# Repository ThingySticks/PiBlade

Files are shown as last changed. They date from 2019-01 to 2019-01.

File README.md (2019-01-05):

# Pi Blade

A 2U high "Blade" center for the Raspberry Pi (or many).

Design inspired by (1) which was inspired by (2) to use the DAP Audio 2 HE Rackblende f. Modulsystem 10 Segmente MP-1 (3), a 2U rack mount system with 10x 44mm wide panels.

## Rack Enclosure

This is the main intended enclosure, if the DAP Audio one isn't available this might be useful, hopefully some add-on bits for the modulsystem as well.

This is made of a number of parts.

* PiRackfrontPanel.svg/dxf - this is a 2U high laser cuttable version of the DAP Audio 2 HE Rackblende f. Modulsystem 10 Segmente MP-1. If you can't get the rack or don't want to wait (or don't mind an acrylic version this might work...

* PiRackRearSide.stl - a 3D printable 1/3 enclosure (side panel). 
** Intended to to around the back of the laser cut panel (not sure how well it will work with the proper rack).
** Print 2x of these, one for each side, then the middle section, these screw to the back of the laser cut acrylic.

## Standalone Enclosure

When getting the Pi's ready you probably don't want to put them in the rack, so this little barn style enclosure allows the blade to be screwed into it to hold it. The Fusion 360 design is scalable to allow multiple units.

* PiBarn-1.stl - 1 blade high
* PiBarn-3.stl - 3 blades high

# Front Panels

These consist of 3D printed panels () and are screwed to the blades.

* McPiFace - is a PCB panel, this can be sent to a fab house such as OSH Park to nicly make the panels.
* Panels from https://www.thingiverse.com/thing:2759317 can also be used and mounted onto the "Blades"

# Blades

These are the carrier frames for the Pi's. Compatible with https://www.thingiverse.com/thing:2759317

* PiRackPiBase.stl - this is the basic Pi blade base.
* PiRackPiLongBase.stl - this will hold 2x Pi's back to back, or HAT base from the Pi Sandwich https://github.com/ThingySticks/PiHatSandwich
** Obviously network connectivity is an issue for the second rear pi when mounting 2x Pi's.

## References

(1) https://www.thingiverse.com/thing:2759317
(2) https://www.thingiverse.com/thing:1793758
(3) https://www.musicstore.de/en_GB/GBP/DAP-Audio-2-HE-Rackblende-f-Modulsystem-10-Segmente-MP-1/art-PAH0017160-000

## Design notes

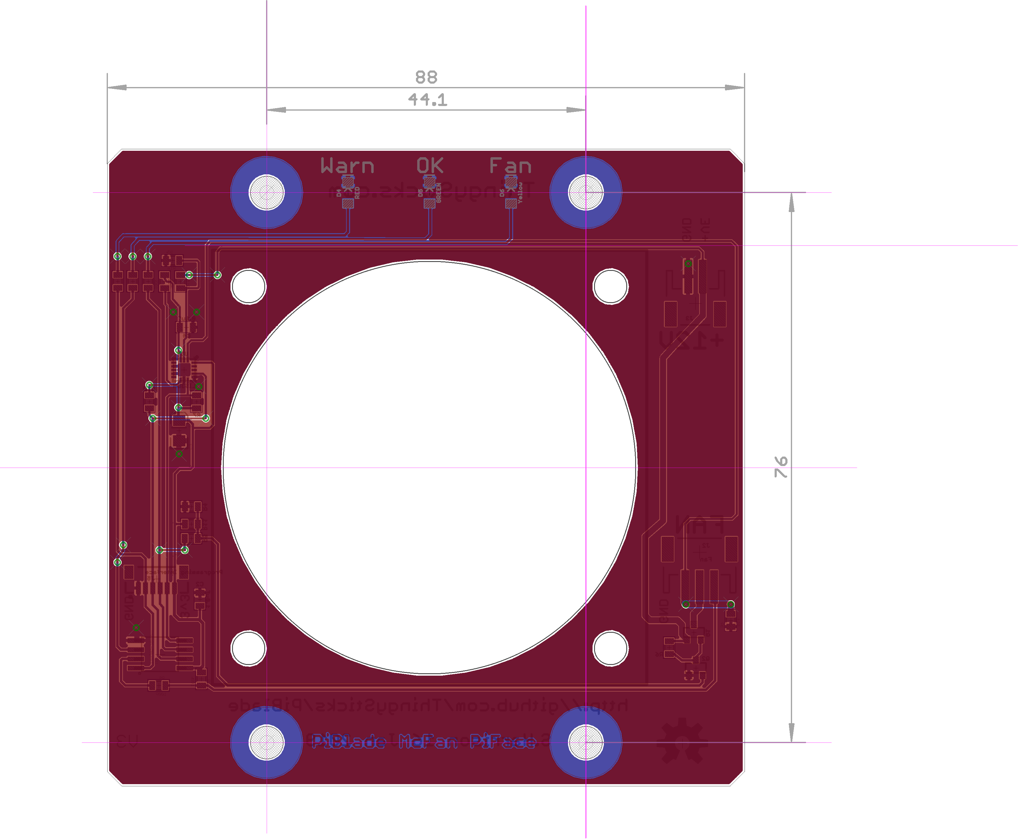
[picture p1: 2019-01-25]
FrontPanels/McPiFace/Images/Fan-V3/PcbAllLayersDesign.png

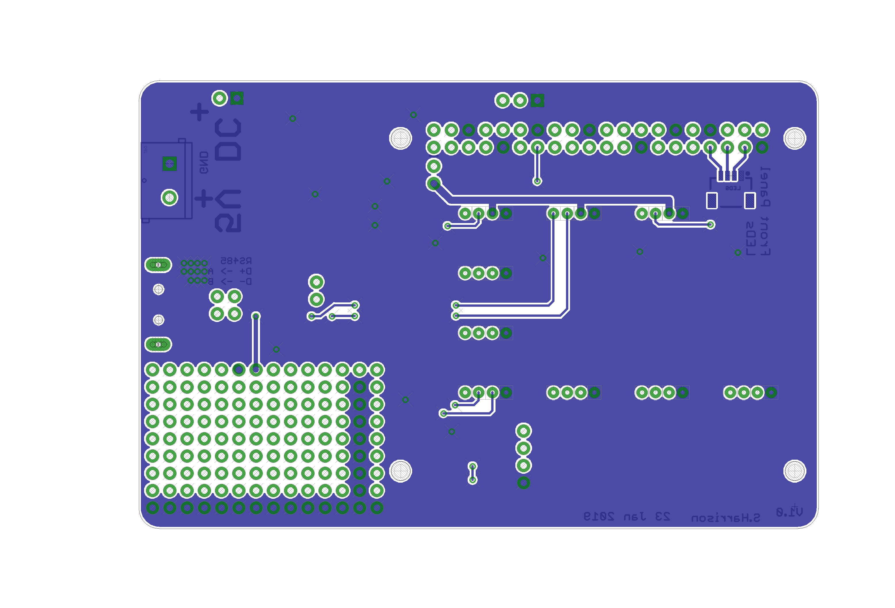
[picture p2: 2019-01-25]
Boards/PiBackPlaneConnector/Images/PcbBottomDesign.png

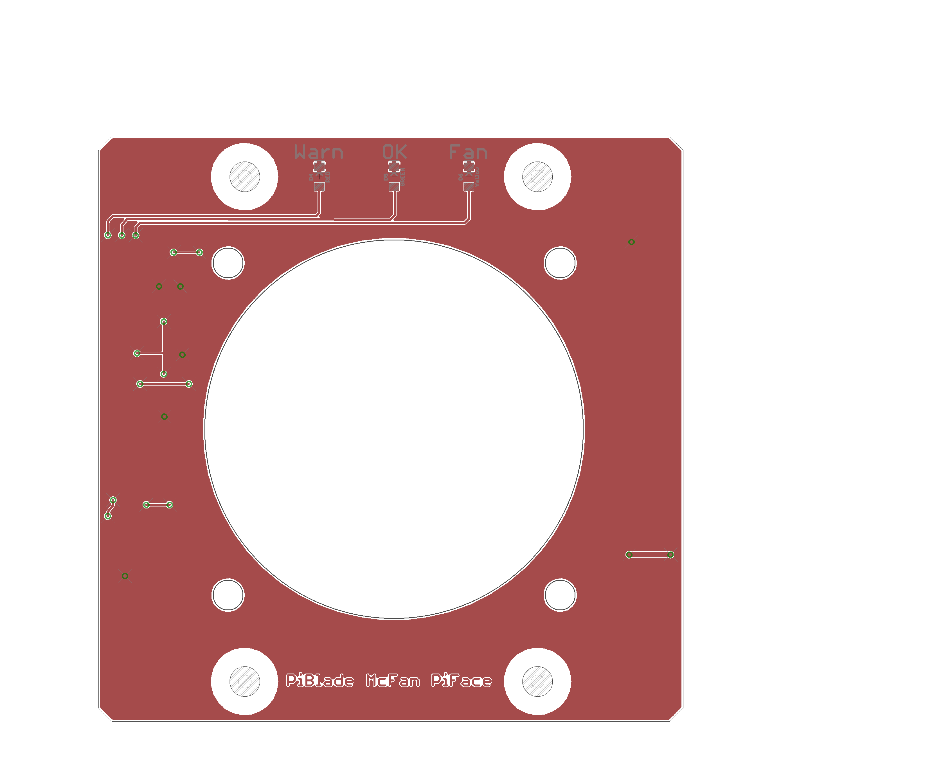
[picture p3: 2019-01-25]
FrontPanels/McPiFace/Images/Fan-V3/PcbTopDesign.png

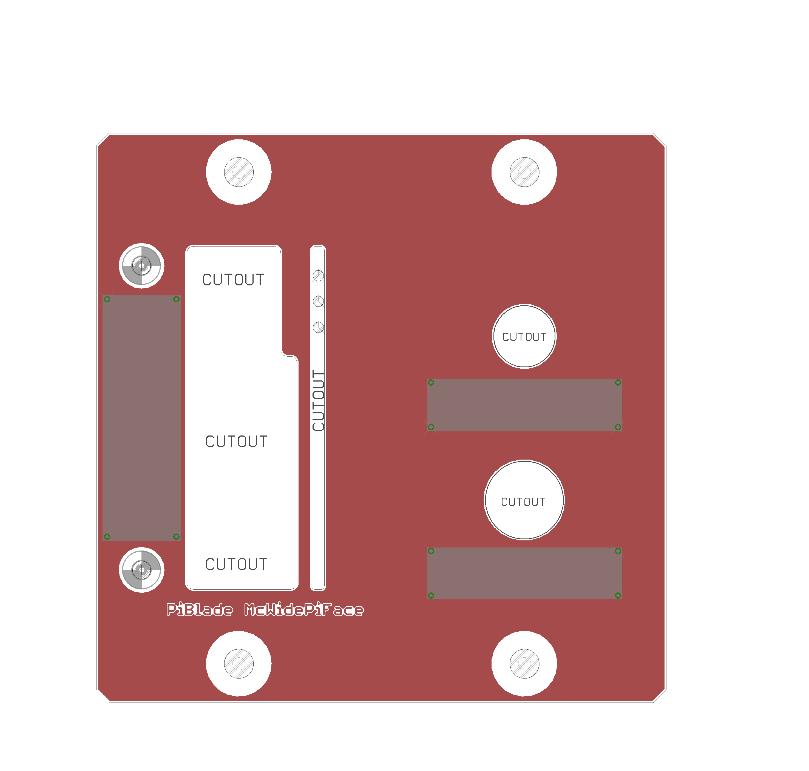
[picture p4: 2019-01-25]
FrontPanels/McPiFace/Images/Double - Aerial/PcbTopDesign.png

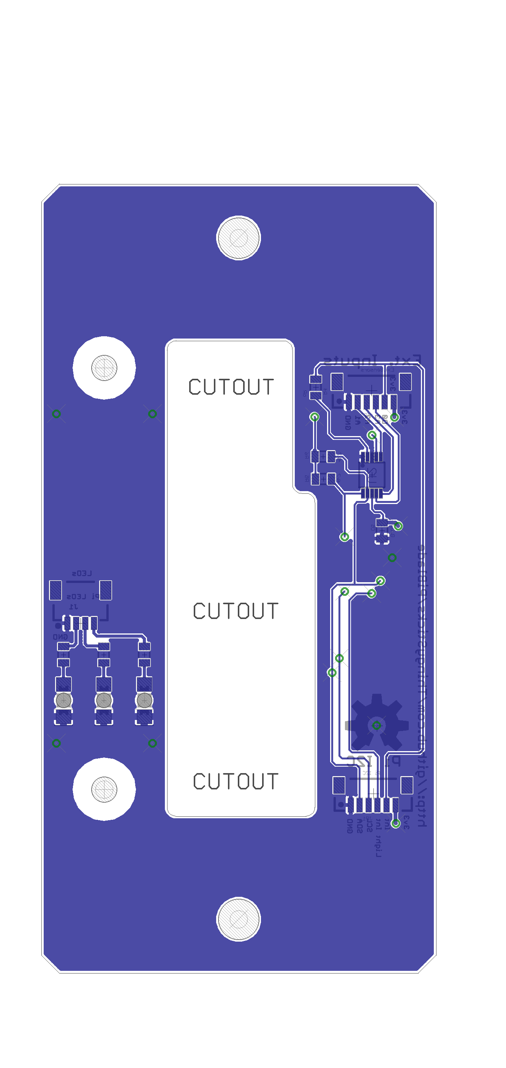
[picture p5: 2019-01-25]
FrontPanels/McPiFace/Images/Environment-V1/PcbBottomDesign.png

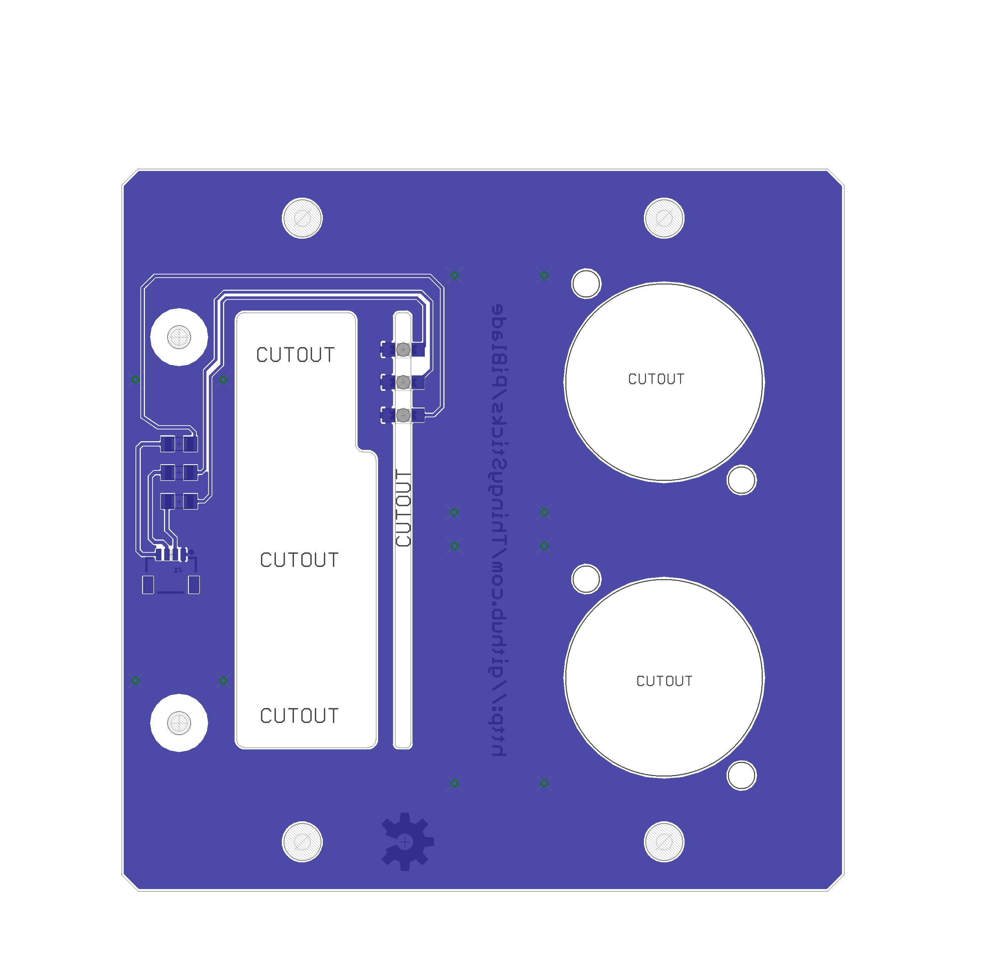
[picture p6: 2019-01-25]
FrontPanels/McPiFace/Images/Audio/PcbBottomDesign.png

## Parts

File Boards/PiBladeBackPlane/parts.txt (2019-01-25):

Partlist

Exported from PiBladeBackPlane-V1.brd at 25/01/2019 11:45

EAGLE Version 7.4.0 Copyright (c) 1988-2015 CadSoft

Assembly variant: 

Part     Value               Package             Library             Position (mm)         Orientation

D1       GREEN               LED-1206            SparkFun-LED        (84.3 28.6)           R0
D2       BLUE                LED-1206            SparkFun-LED        (15.1 3.5)            R0
D3       BLUE                LED-1206            SparkFun-LED        (42.3 3.6)            R0
D4       BLUE                LED-1206            SparkFun-LED        (84.3 3.7)            R0
J1                           MOLEX-1X3           SparkFun-Connectors (28.56 28.82)         R0
J2                           MOLEX-1X3           SparkFun-Connectors (58.17 28.92)         R0
J4                           JST-2-SMD-VERT      SparkFun-Connectors (23.64 3.12)          R180
J5                           JST-2-SMD-VERT      SparkFun-Connectors (61.03 3.12)          R180
J7                           SCREWTERMINAL-5MM-2 SparkFun-Connectors (71.59 19.89)         R180
J8                           JST-4-PTH-VERT      SparkFun-Connectors (94.88 29.57)         R0
J9                           JST-4-PTH-VERT      SparkFun-Connectors (13.28 29.61)         R0
JP1      USB-NEW             USB-A-VERTICAL      Tinamous            (5 16)                MR0
JP2      USB-NEW             USB-A-VERTICAL      Tinamous            (46.1 16)             MR0
JP3      USB-NEW             USB-A-VERTICAL      Tinamous            (90.2 16)             MR0
R1                           1206                SparkFun-Resistors  (78.6 28.6)           R0
R2                           1206                SparkFun-Resistors  (10.6 4.9)            R270
R3                           1206                SparkFun-Resistors  (37.6 5)              R270
R4                           1206                SparkFun-Resistors  (79.4 5.1)            R270
U$1      MINI-BUCK-MODULE-3A MINI-BUCK-MODULE-3A Tinamous            (8.83 24.33)          MR180
U$2      MINI-BUCK-MODULE-3A MINI-BUCK-MODULE-3A Tinamous            (35.83 24.33)         MR180
U$3      MINI-BUCK-MODULE-3A MINI-BUCK-MODULE-3A Tinamous            (77.63 24.38)         MR180

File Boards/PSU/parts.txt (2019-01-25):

Partlist

Exported from PiBladePsuInput.brd at 25/01/2019 11:47

EAGLE Version 7.4.0 Copyright (c) 1988-2015 CadSoft

Assembly variant: 

Part     Value            Package                      Library               Position (mm)         Orientation

12V      RELAYSONGLE      SRD-5VDC-SL-C                ThingySticks          (23.12 40.35)         R0
C1       1.0uF            0805                         SparkFun-Capacitors   (38.5 21.7)           R90
C2       0.1uF            0805                         SparkFun-Capacitors   (38.5 26.4)           R270
C3       1.0uF            0805                         SparkFun-Capacitors   (62.5 47.3)           R90
C4       0.1uF            0805                         SparkFun-Capacitors   (77.1 47.5)           R0
C5       0.1uF            0805                         SparkFun-Capacitors   (61.8 35.8)           R180
C6       0.1uF            0805                         SparkFun-Capacitors   (65.7 42)             R270
D1       1A/23V/620mV     SOD-323                      SparkFun-DiscreteSemi (35.2 45.2)           R90
D2       1A/23V/620mV     SOD-323                      SparkFun-DiscreteSemi (36.4 37.3)           R0
D3       1A/23V/620mV     SOD-323                      SparkFun-DiscreteSemi (35.3 20)             R0
D4       BLUE             LED-1206                     SparkFun-LED          (77.8 1.9)            R0
D5       BLUE             LED-1206                     SparkFun-LED          (57.7 27.8)           R270
D6       BLUE             LED-1206                     SparkFun-LED          (81.1 48.5)           R270
D7       BLUE             LED-1206                     SparkFun-LED          (10.2 35.2)           R0
D8       BLUE             LED-1206                     SparkFun-LED          (10.1 20.2)           R0
D9       BLUE             LED-1206                     SparkFun-LED          (10.1 5.9)            R0
J1       CONN_20X2NOSILK  2X20_NOSILK                  SparkFun-Connectors   (8.4 51.2)            R0
J2                        1X06-1MM                     SparkFun-Connectors   (66.2 28.1)           MR0
J3                        1X04_1MM_RA                  SparkFun-Connectors   (44.2 30.8)           MR180
JP1      POWER_JACKTOE    POWER_JACK_SMD_OVERPASTE_TOE SparkFun-Connectors   (81.6 19)             R180
JP2                       SCREWTERMINAL-5MM-2          SparkFun-Connectors   (80.78 39.67)         R270
JP3                       SCREWTERMINAL-5MM-2          SparkFun-Connectors   (4.22 40.33)          R90
JP4                       SCREWTERMINAL-5MM-2          SparkFun-Connectors   (4.32 25.23)          R90
JP5                       SCREWTERMINAL-5MM-2          SparkFun-Connectors   (4.22 10.83)          R90
JP6      USB-NEW          USB-A-VERTICAL               Tinamous              (54.7 29)             R180
Q1       220mA/50V/3.5?   SOT23-3                      SparkFun-DiscreteSemi (38.96 46.32)         R90
Q2       220mA/50V/3.5?   SOT23-3                      SparkFun-DiscreteSemi (38.86 40.34)         R90
Q3       220mA/50V/3.5?   SOT23-3                      SparkFun-DiscreteSemi (38.86 34.66)         R90
R1       4k7              0805                         SparkFun-Resistors    (69.6 36.1)           R270
R2       4k7              0805                         SparkFun-Resistors    (67.6 36.1)           R270
R3                        0805                         SparkFun-Resistors    (72 1.9)              R0
R4                        0805                         SparkFun-Resistors    (57.7 31.9)           R270
R5                        0805                         SparkFun-Resistors    (77.1 50)             R0
R6                        0805                         SparkFun-Resistors    (5.2 35.2)            R0
R7       0.05             2512                         SparkFun-Resistors    (61.54 17.01)         R180
R8       1M               0805                         SparkFun-Resistors    (46.6 34.59)          R90
R9       1M               0805                         SparkFun-Resistors    (46.6 38.52)          R270
R10      1M               0805                         SparkFun-Resistors    (46.37 45.4)          R0
R11                       0805                         SparkFun-Resistors    (5.2 20.2)            R0
R12                       0805                         SparkFun-Resistors    (9.8 3.2)             R0
U$2      RELAYSONGLE      SRD-5VDC-SL-C                ThingySticks          (23.14 24.14)         R0
U$3      RELAYSONGLE      SRD-5VDC-SL-C                ThingySticks          (23.12 7.94)          R0
U1       INA219AIDCNRSOIC SO08                         INA219AIDCNR          (66.16 30.62)         R90
U2       R-78E5.0-1.0     DC-DC_CONVERTER_78XX         SparkFun-IC-Power     (46.2 26.1)           R90
U3                        SOT223                       SparkFun-PowerIC      (70 47.5)             R270
U4       Tiny85-20-SMT    SO08-EIAJ                    SparkFun-DigitalIC    (58 41.8)             R270

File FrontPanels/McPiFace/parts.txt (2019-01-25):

Partlist

Exported from McParticleEthernetFace-V1.brd at 25/01/2019 12:06

EAGLE Version 7.4.0 Copyright (c) 1988-2015 CadSoft

Assembly variant: 

Part     Value          Package               Library             Position (mm)         Orientation

D1                      LED-1206-BOTTOM-1.6MM ThingySticks        (32.54 67.58)         MR90
D2                      LED-1206-BOTTOM-1.6MM ThingySticks        (37.04 67.58)         MR90
D3                      LED-1206-BOTTOM-1.6MM ThingySticks        (41.54 67.58)         MR90
J1                      1X04_1MM_RA           SparkFun-Connectors (39.64 58.68)         MR0
R1                      0805                  SparkFun-Resistors  (41.54 62.18)         MR90
R2                      0805                  SparkFun-Resistors  (37.04 62.18)         MR90
R3                      0805                  SparkFun-Resistors  (32.54 62.18)         MR90

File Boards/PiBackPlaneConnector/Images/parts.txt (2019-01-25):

Partlist

Exported from PiBackPlaneConnector-V1.brd at 25/01/2019 11:44

EAGLE Version 7.4.0 Copyright (c) 1988-2015 CadSoft

Assembly variant: 

Part        Value                               Package                      Library                Position (mm)         Orientation

A                                               1X02                         SparkFun-Connectors    (-20.955 29.21)       R180
B                                               1X02                         SparkFun-Connectors    (-20.955 26.67)       R180
BUTTONS                                         1X06-1MM                     SparkFun-Connectors    (56 32.4)             R0
C1          0.1uF                               0805                         SparkFun-Capacitors    (-16.9 21.4)          R0
C2          0.1uF                               0805                         SparkFun-Capacitors    (0.7 43.9)            R180
C3          1.0uF                               0805                         SparkFun-Capacitors    (3.37 55.965)         R0
C4          0.1uF                               0805                         SparkFun-Capacitors    (-7.2 44.3)           R180
C5          0.1uF                               0805                         SparkFun-Capacitors    (5.1 15.7)            R180
D5          BLUE                                LED-1206                     SparkFun-LED           (-30.5 59.9)          R180
D6          BLUE                                LED-1206                     SparkFun-LED           (-9.4 55.4)           R180
DISPLAY     DISPLAY0.91_INCH_DISPLAY            I2C_DISPLAY_0.91_INCH        ThingySticks           (20.1 -0.4)           R0
GPIO-1                                          JST-4-PTH-VERT               SparkFun-Connectors    (42 15.6)             R0
GPIO-2                                          JST-4-PTH-VERT               SparkFun-Connectors    (29 15.6)             R0
GPIO-3                                          JST-4-PTH-VERT               SparkFun-Connectors    (55 15.6)             R0
GREEN_LEDS                                      1X06-1MM                     SparkFun-Connectors    (28.9 32.3)           R0
I2C-1                                           JST-4-PTH-VERT               SparkFun-Connectors    (16 42)               R0
I2C-2                                           JST-4-PTH-VERT               SparkFun-Connectors    (16 33.2)             R0
I2C-3                                           JST-4-PTH-VERT               SparkFun-Connectors    (16 24.4)             R0
I2C-4                                           JST-4-PTH-VERT               SparkFun-Connectors    (16 15.6)             R0
J1          CONN_20X2NOSILK                     2X20_NOSILK                  SparkFun-Connectors    (8.4 51.2)            R0
J2                                              MOLEX-1X2                    SparkFun-Connectors    (-20.6 58.4)          R180
J3                                              1X14                         SparkFun-Connectors    (-33.02 18.415)       R0
J4          USB_A_SMT_MALE                      USB-A-SMT-MALE               Tinamous               (-40.3 28)            R0
J7                                              1X02                         SparkFun-Connectors    (8.4 48.4)            R270
J8                                              1X14                         SparkFun-Connectors    (-33.02 -1.905)       R0
J9                                              1X14_NO_SILK                 SparkFun-Connectors    (-33.02 15.875)       R0
J10                                             1X14_NO_SILK                 SparkFun-Connectors    (-33.02 13.335)       R0
J11                                             1X14_NO_SILK                 SparkFun-Connectors    (-33.02 10.795)       R0
J12                                             1X14_NO_SILK                 SparkFun-Connectors    (-33.02 8.255)        R0
J13                                             1X14_NO_SILK                 SparkFun-Connectors    (-33.02 5.715)        R0
J14                                             1X14_NO_SILK                 SparkFun-Connectors    (-33.02 3.175)        R0
J15                                             1X14_NO_SILK                 SparkFun-Connectors    (-33.02 0.635)        R0
JP2                                             SCREWTERMINAL-5MM-2@1        SparkFun-Connectors    (-30.52 48.77)        MR270
LEDS                                            1X04_1MM_RA                  SparkFun-Connectors    (52.1 47)             MR0
MC_I2C_PORT                                     1X06-1MM                     SparkFun-Connectors    (13.6 6.3)            R0
NEOPIXELS                                       MOLEX-1X3                    SparkFun-Connectors    (23.6 58.1)           R180
PWM                                             JST-4-PTH-VERT               SparkFun-Connectors    (42 42)               R0
R1          0.1                                 1210                         SparkFun-Resistors     (-3.7 58.1)           R0
R2          10k                                 0805                         SparkFun-Resistors     (-6.6 32.2)           R90
R3                                              0805                         SparkFun-Resistors     (27.2 58.8)           R0
R4          1k5                                 0805                         SparkFun-Resistors     (-26.4 59.9)          R180
R5          1k                                  0805                         SparkFun-Resistors     (-7.9 52.5)           R90
R6          10k                                 0805                         SparkFun-Resistors     (26.7 9.5)            R180
R7          10k                                 0805                         SparkFun-Resistors     (26.7 6.9)            R180
RED_LEDS                                        1X06-1MM                     SparkFun-Connectors    (41.6 32.4)           R0
RTS                                             1X02                         SparkFun-Connectors    (-8.9 28.8)           R90
SERIAL                                          JST-4-PTH-VERT               SparkFun-Connectors    (29 42)               R0
SHUTDOWN    MOMENTARY-SWITCH-SPST-SMD-6.0X3.5MM TACTILE_SWITCH_SMD_6.0X3.5MM ThingySticks           (42 57.9)             R180
U1           MAX3485CSA                         SO08                         SparkFun-IC-Comms      (-14 28.2)            R90
U2          INA219AIDCNRSOIC                    SO08                         INA219AIDCNR           (4.3 39)              R90
U3                                              SOT223                       SparkFun-PowerIC       (-3.2 48.5)           R90
U4          SN74AHC1G125                        SOT23-5                      SparkFun-IC-Logic      (31.5 57.8)           R90
U5          ADS1015                             MSOP10                       SparkFun-IC-Conversion (5.1 12)              R270

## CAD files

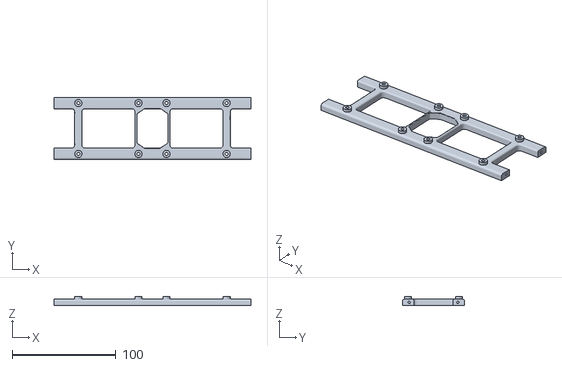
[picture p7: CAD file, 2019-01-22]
Blades/PiRackPiLongBase.stl
190.0 x 60.0 x 8.50

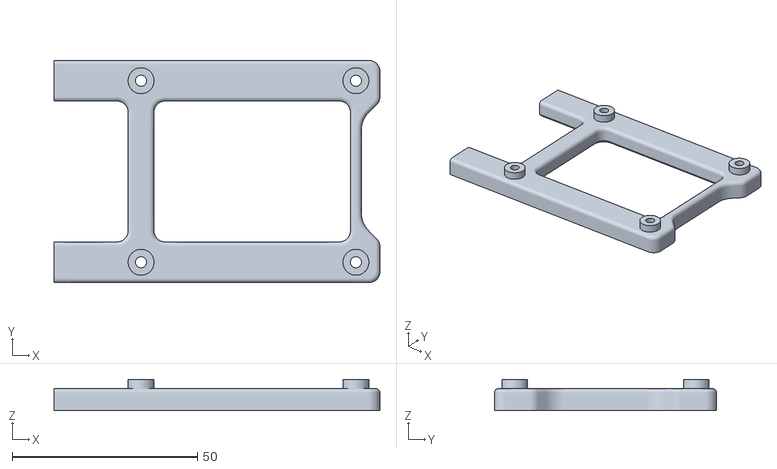
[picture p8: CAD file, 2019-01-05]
Blades/PiRackPiBase.stl
88.0 x 60.0 x 8.50

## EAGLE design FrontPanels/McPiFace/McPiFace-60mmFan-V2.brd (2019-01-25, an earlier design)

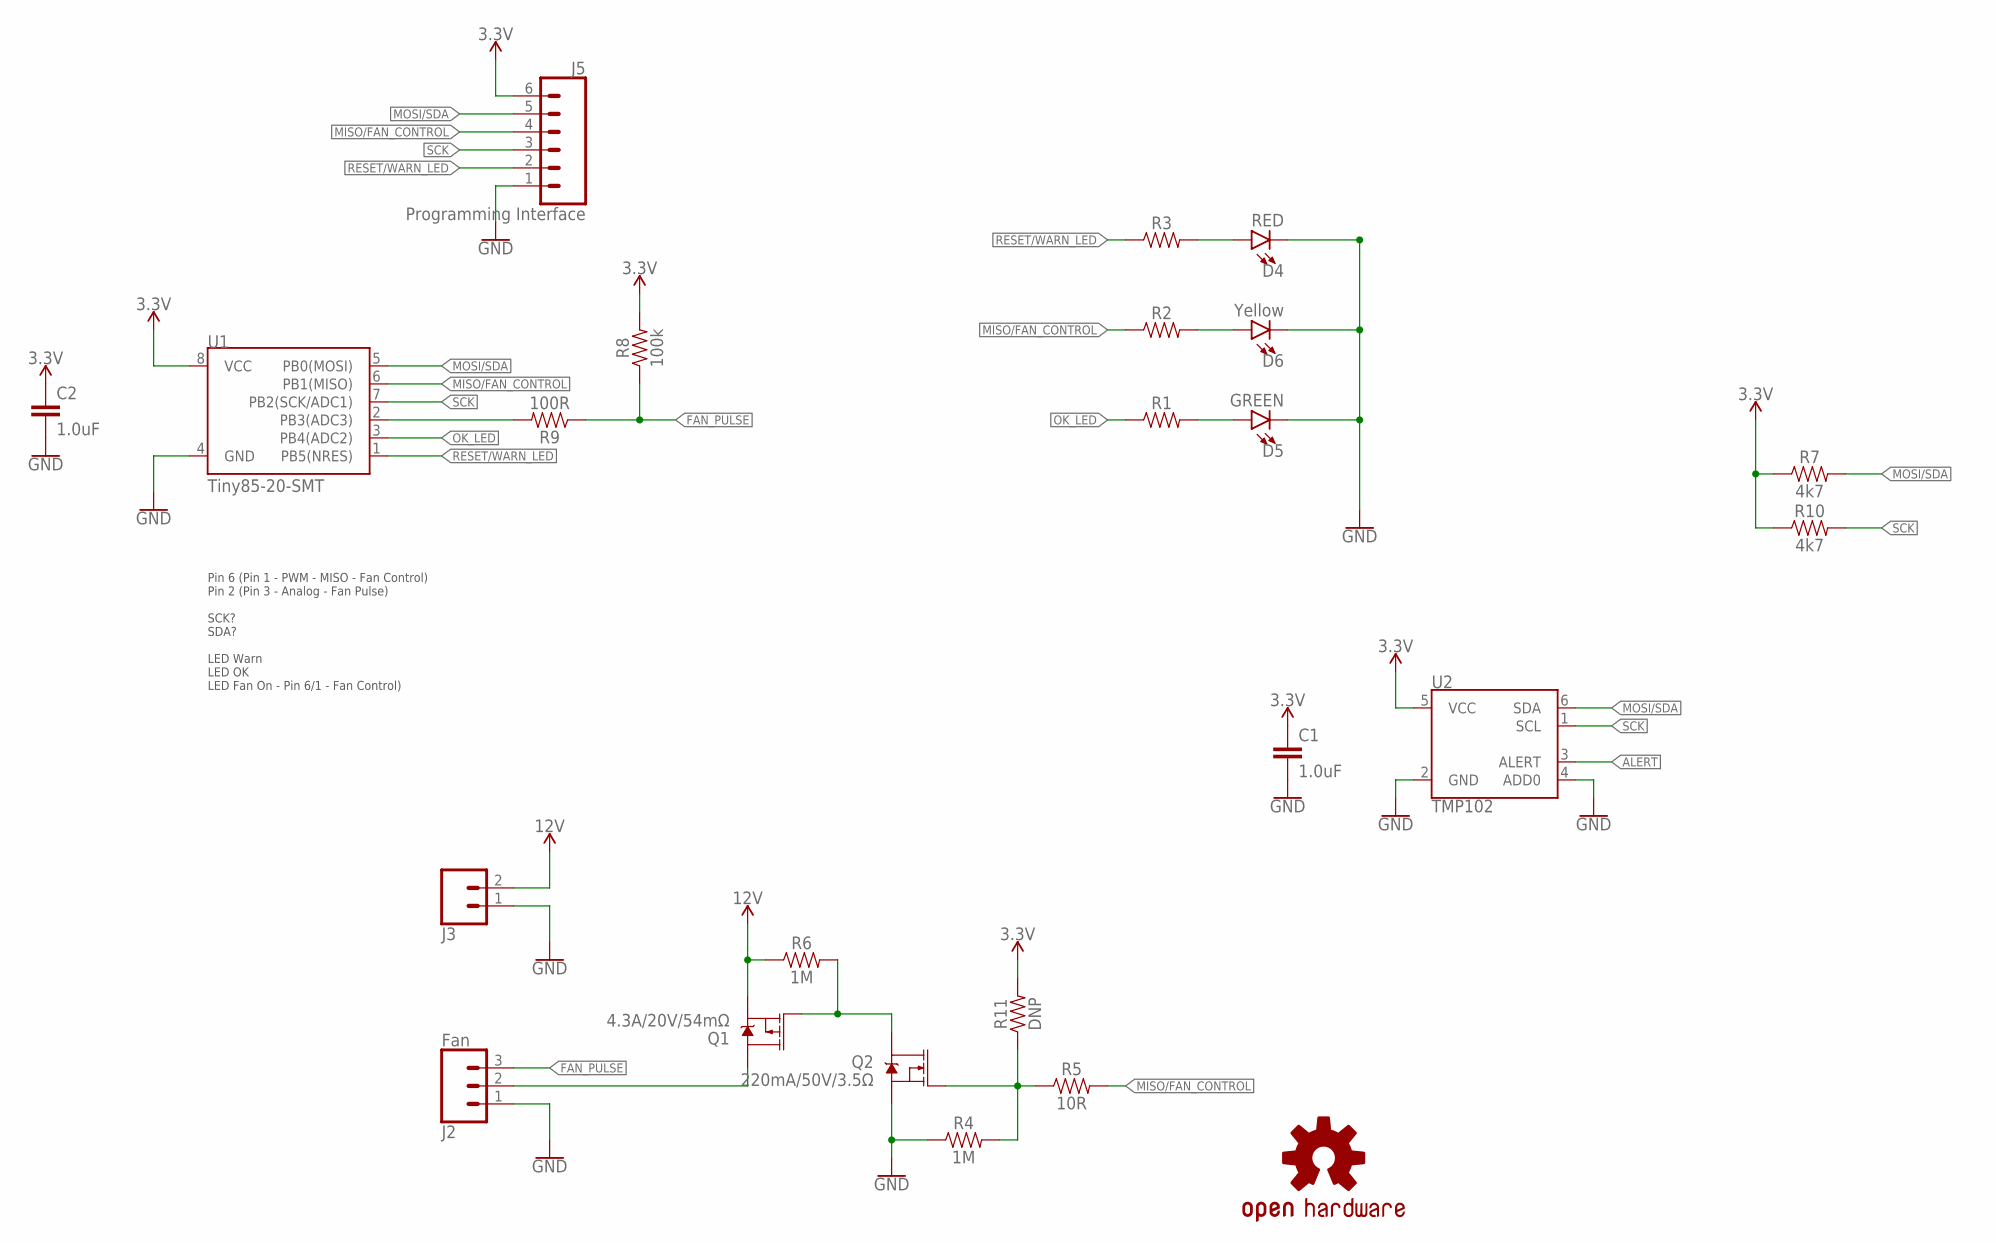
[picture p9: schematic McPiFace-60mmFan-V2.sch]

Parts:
C1, C2: 1.0uF; 0805
D4: RED; LED-1206
D5: GREEN; LED-1206
D6: Yellow; LED-1206
J2: Fan; JST-3-SMD; FARNELL 9492623
J3: CONN_02-JST-2MM-SMT; JST-2-SMD; FARNELL 9492615
J5: Programming Interface; 1X06-1MM
LOGO1: OSHW-LOGOL; OSHW-LOGO-L
Q1: 4.3A/20V/54mΩ; SOT23-3
Q2: 220mA/50V/3.5Ω; SOT23-3
R1, R2, R3: 1206
R4, R6: 1M; 0805
R5: 10R; 0805
R7, R10: 4k7; 0805
R8: 100k; 0805
R9: 100R; 0805
R11: DNP; 0805
U1: Tiny85-20-SMT; SO08-EIAJ
U2: TMP102; SOT563

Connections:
3.3V: C1.1, C2.1, J5.6, R7.1, R8.2, R10.1, R11.2, U1.8 (VCC), U2.5 (VCC)
12V: J3.2 (1), Q1.2 (S), R6.1
ALERT: U2.3 (ALERT)
FAN_PULSE: J2.3 (1), R8.1, R9.1
GND: C1.2, C2.2, D4.C, D5.C, D6.C, J2.1 (3), J3.1 (2), J5.1, Q2.2 (S), R4.1, U1.4 (GND), U2.2 (GND), U2.4 (ADD0)
MISO/FAN_CONTROL: J5.4, R2.1, R5.2, U1.6 (PB1(MISO))
MOSI/SDA: J5.5, R7.2, U1.5 (PB0(MOSI)), U2.6 (SDA)
unnamed: R9.2, U1.2 (PB3(ADC3))
unnamed: D4.A, R3.2
unnamed: D6.A, R2.2
unnamed: D5.A, R1.2
unnamed: J2.2, Q1.3 (D)
unnamed: Q1.1 (G), Q2.3 (D), R6.2
unnamed: Q2.1 (G), R4.2, R5.1, R11.1
OK_LED: R1.1, U1.3 (PB4(ADC2))
RESET/WARN_LED: J5.2, R3.1, U1.1 (PB5(NRES))
SCK: J5.3, R10.2, U1.7 (PB2(SCK/ADC1)), U2.1 (SCL)

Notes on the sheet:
Pin 6 (Pin 1 - PWM - MISO - Fan Control) Pin 2 (Pin 3 - Analog - Fan Pulse) SCK? SDA? LED Warn LED OK LED Fan On - Pin 6/1 - Fan Control)

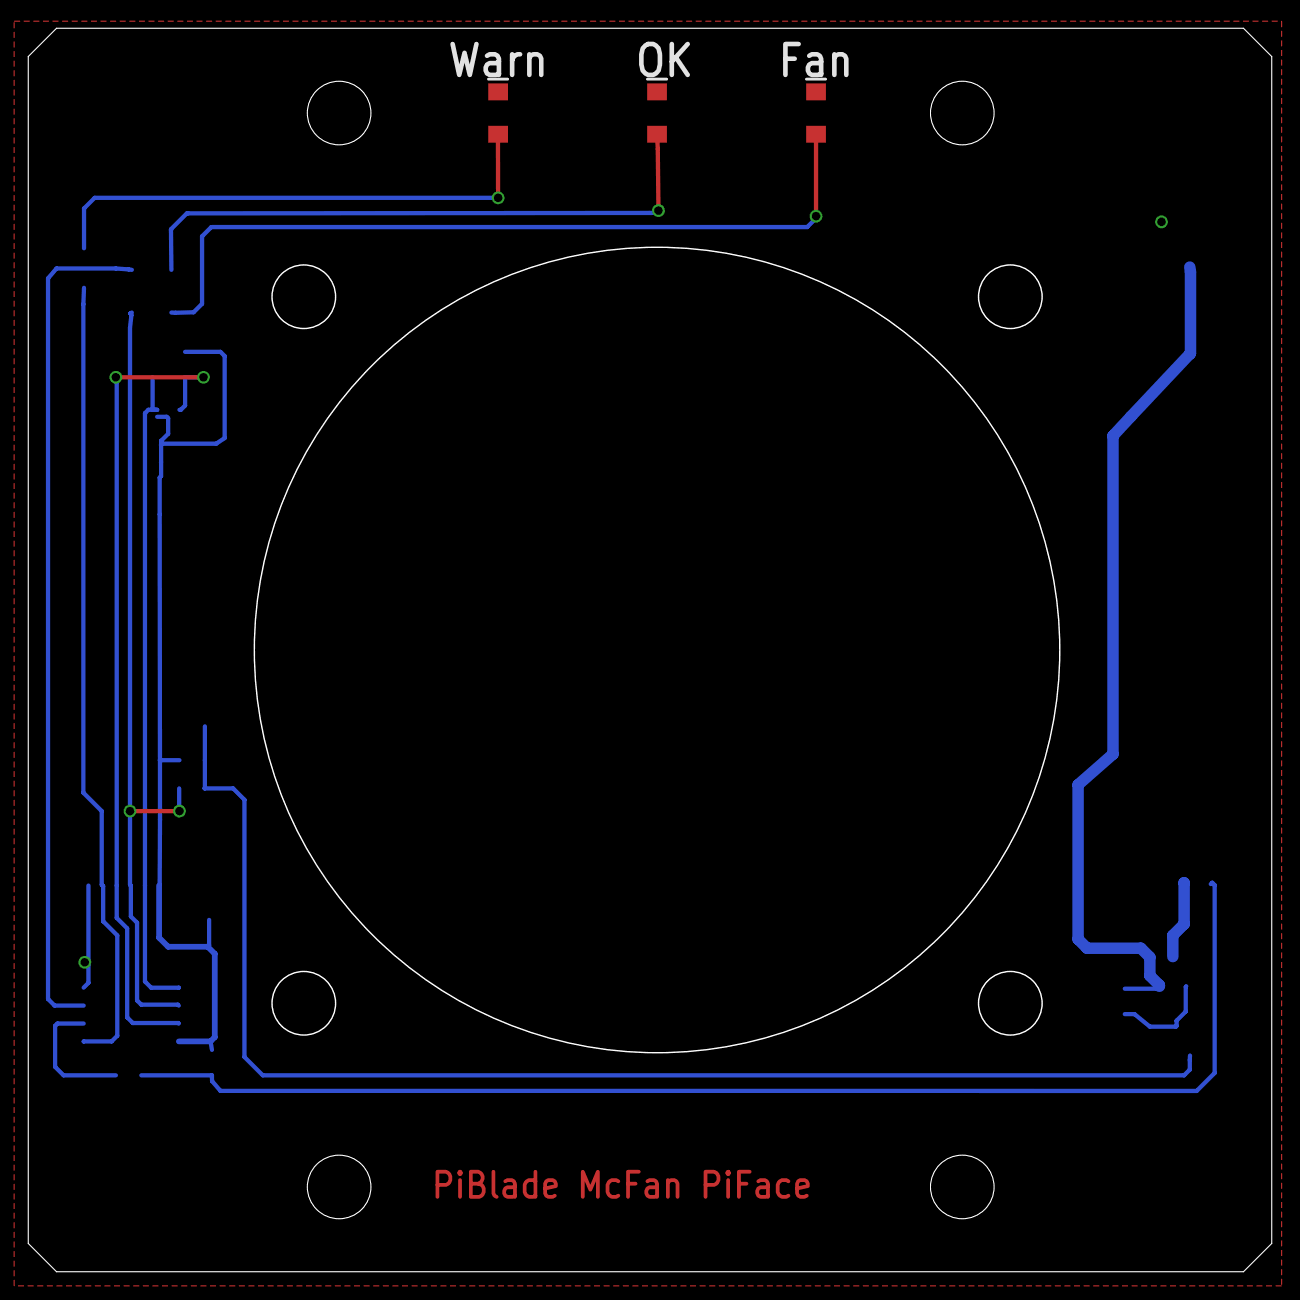
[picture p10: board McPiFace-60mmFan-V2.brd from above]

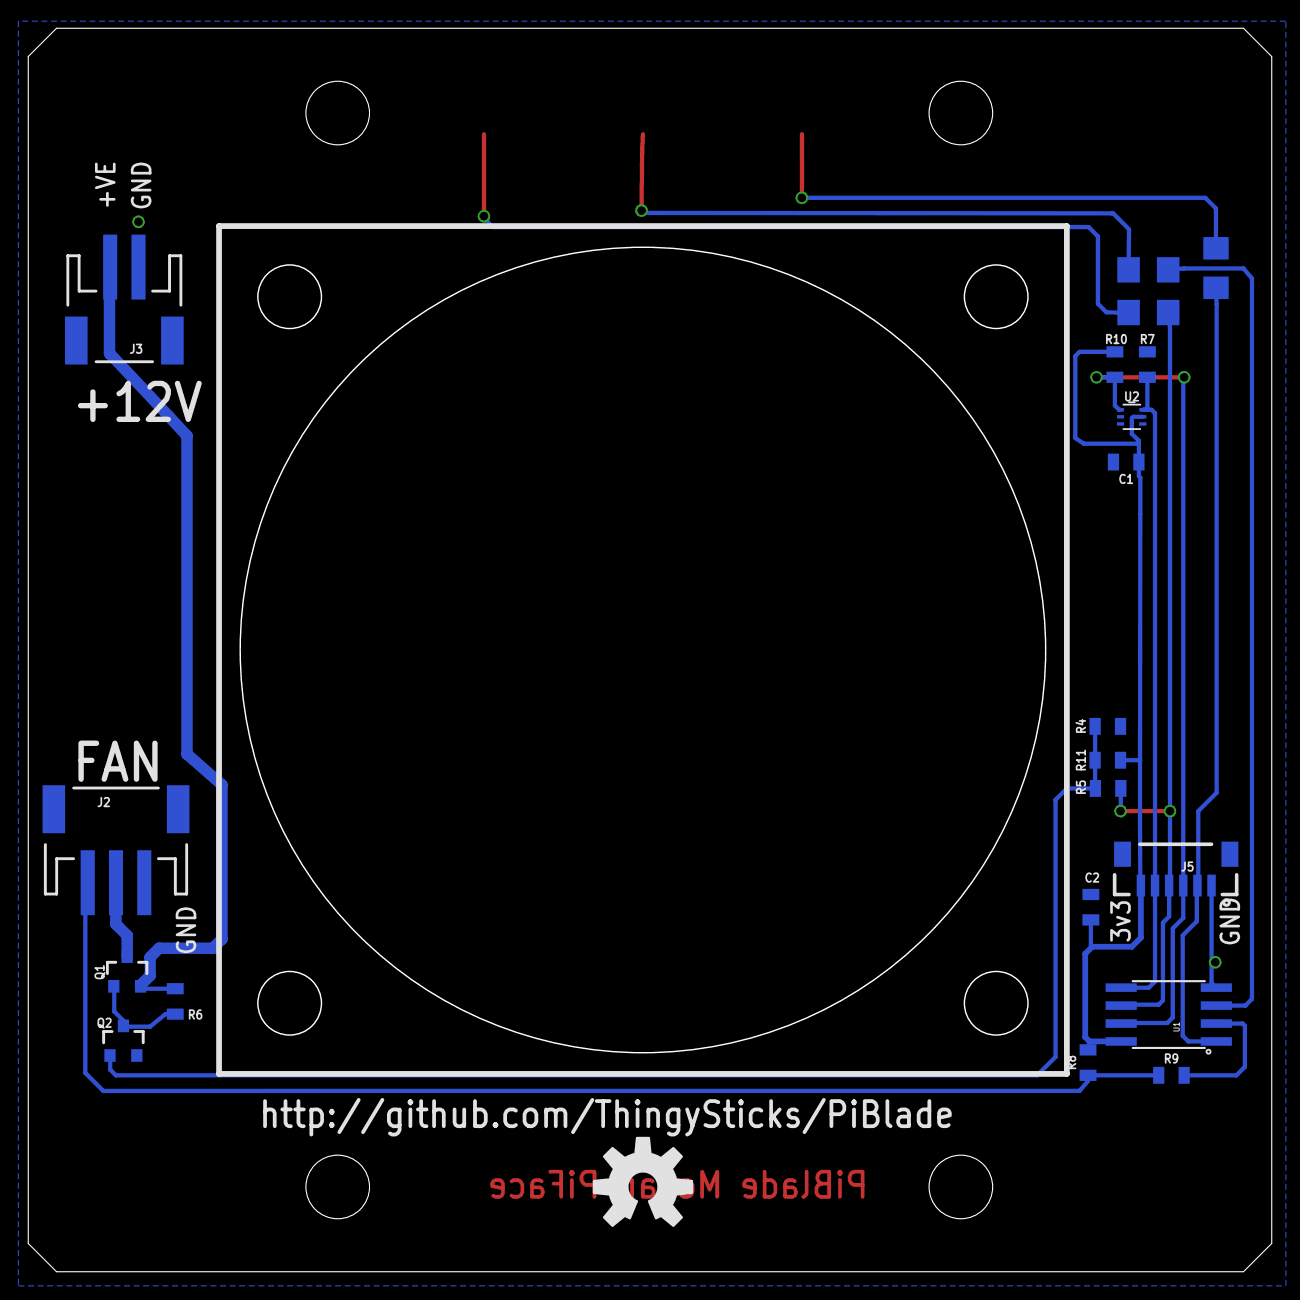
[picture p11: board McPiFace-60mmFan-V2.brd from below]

Board: 2 copper layers, 88.0 x 88.0 mm, 24 parts (21 on the bottom side), 16 nets.

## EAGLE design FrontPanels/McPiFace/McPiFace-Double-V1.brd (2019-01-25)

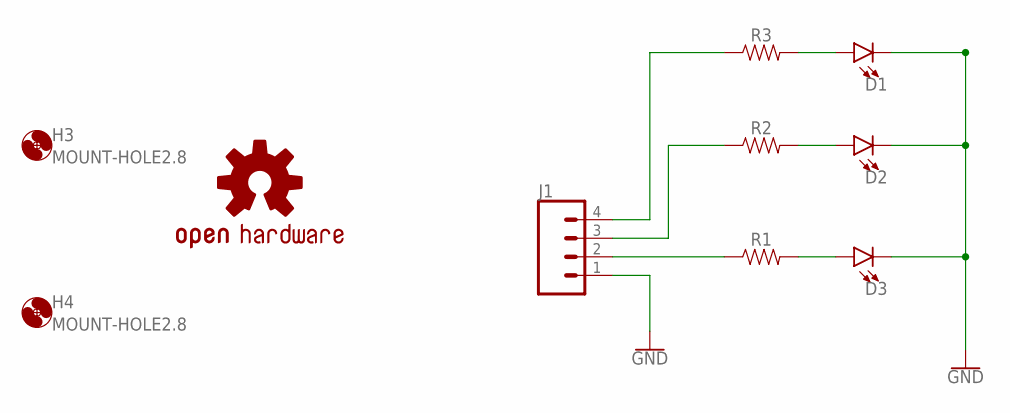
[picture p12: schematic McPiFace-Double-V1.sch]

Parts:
D1, D2, D3: LED1206-BOTTOM-1.6MM; LED-1206-BOTTOM-1.6MM
H3, H4: MOUNT-HOLE2.8; 2,8
J1: CONN_04SMD2; 1X04_1MM_RA
LOGO1: OSHW-LOGOL; OSHW-LOGO-L
R1, R2, R3: 1206

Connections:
GND: D1.C, D2.C, D3.C, J1.1
unnamed: D1.A, R3.2
unnamed: D2.A, R2.2
unnamed: D3.A, R1.2
unnamed: J1.2, R1.1
unnamed: J1.3, R2.1
unnamed: J1.4, R3.1

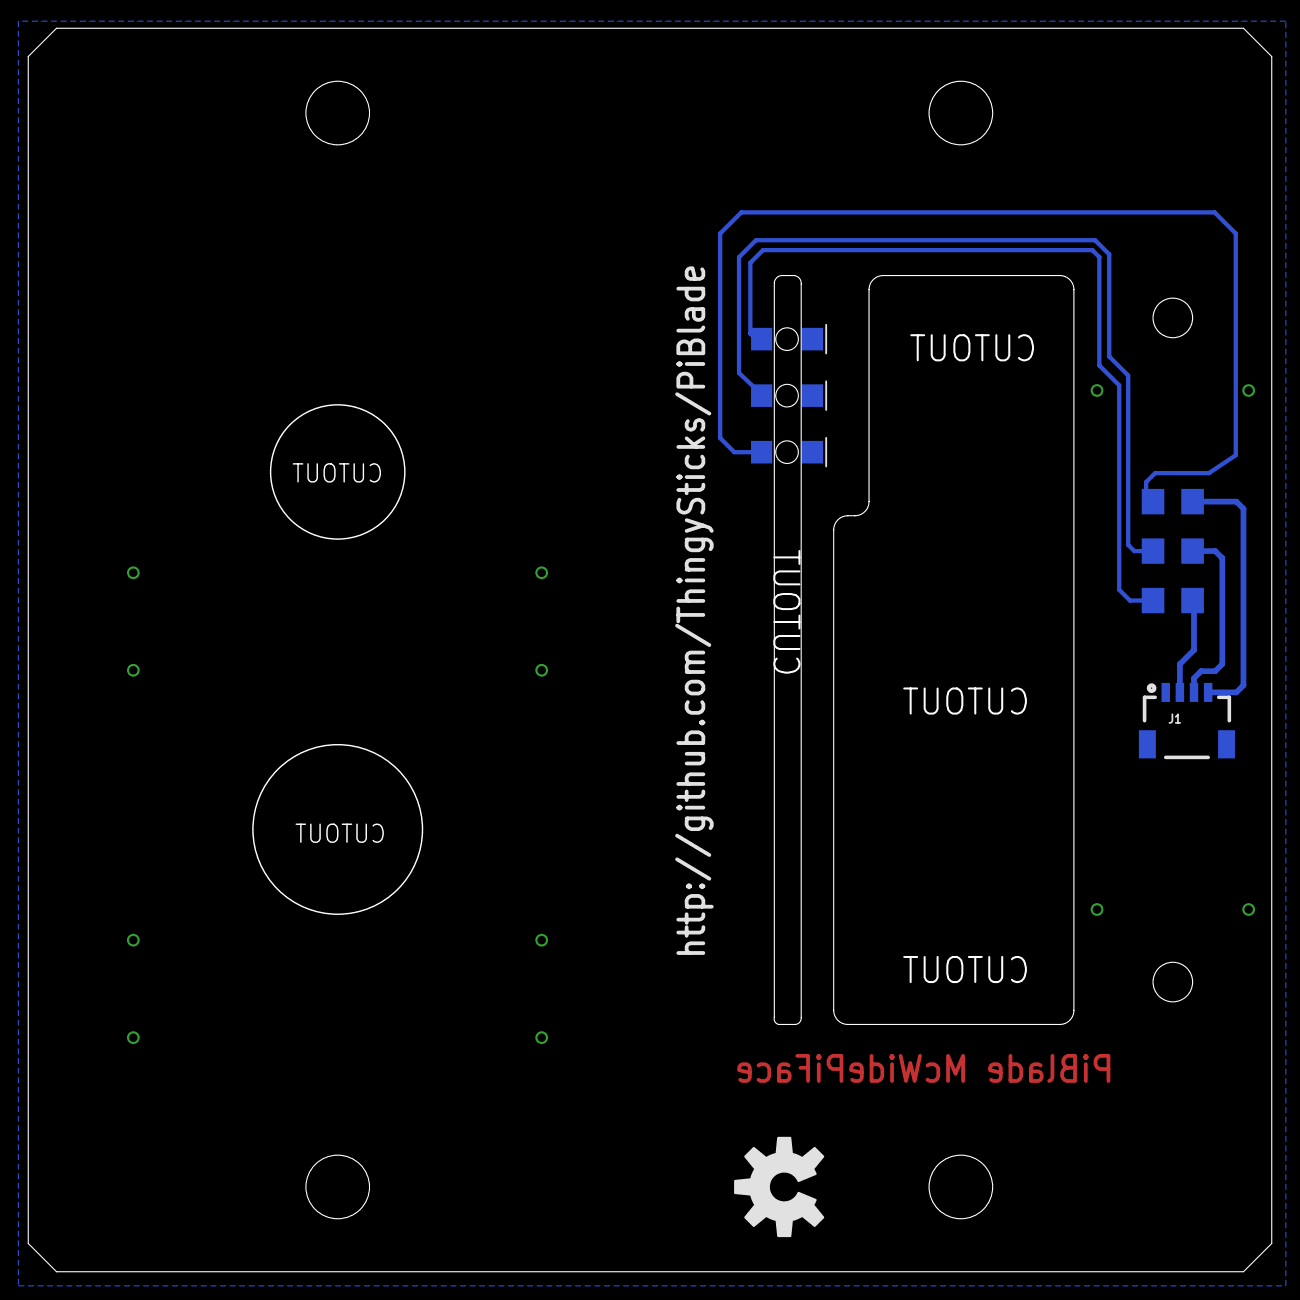
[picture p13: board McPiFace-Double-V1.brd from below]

Board: 2 copper layers, 88.0 x 88.0 mm, 10 parts (8 on the bottom side), 7 nets.

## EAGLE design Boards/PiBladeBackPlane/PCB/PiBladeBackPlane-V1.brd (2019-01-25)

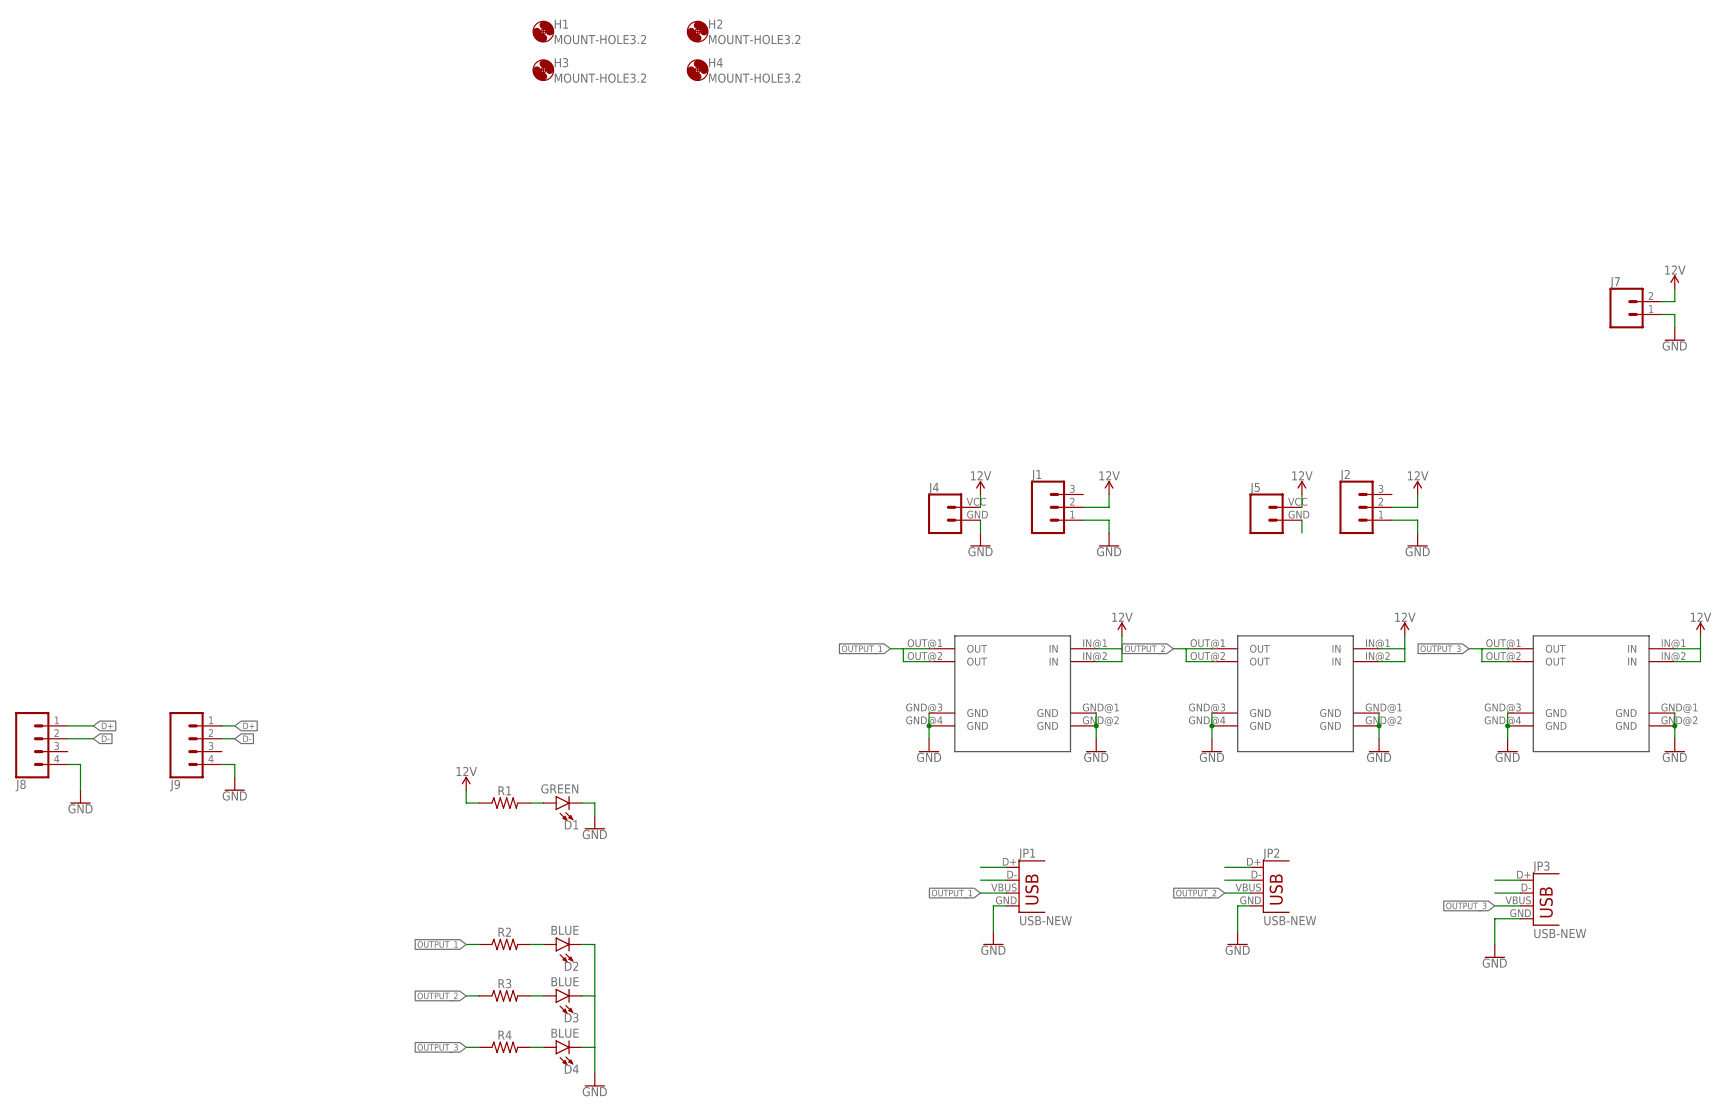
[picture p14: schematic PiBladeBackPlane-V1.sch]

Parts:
D1: GREEN; LED-1206
D2, D3, D4: BLUE; LED-1206
H1, H2, H3, H4: MOUNT-HOLE3.2; 3,2
J1, J2: CONN_03POLAR; MOLEX-1X3
J4, J5: CONN_024UCON-15767; JST-2-SMD-VERT
J7: CONN_025MM; SCREWTERMINAL-5MM-2
J8, J9: CONN_04JST-PTH-VERT; JST-4-PTH-VERT
JP1, JP2, JP3: USB-NEW; USB-A-VERTICAL
R1, R2, R3, R4: 1206
U$1, U$2, U$3: MINI-BUCK-MODULE-3A

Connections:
12V: J1.2, J2.2, J4.VCC (2), J5.VCC (2), J7.2, R1.1, U$1.IN@1 (IN), U$1.IN@2 (IN), U$2.IN@1 (IN), U$2.IN@2 (IN), U$3.IN@1 (IN), U$3.IN@2 (IN)
D+: J8.1, J9.1, JP1.D+, JP2.D+, JP3.D+
D-: J8.2, J9.2, JP1.D-, JP2.D-, JP3.D-
GND: D1.C, D2.C, D3.C, D4.C, J1.1, J2.1, J4.GND (1), J7.1, J8.4, JP1.GND, JP2.GND, JP3.GND, U$1.GND@1 (GND), U$1.GND@2 (GND), U$1.GND@3 (GND), U$1.GND@4 (GND), U$2.GND@1 (GND), U$2.GND@2 (GND), U$2.GND@3 (GND), U$2.GND@4 (GND), U$3.GND@1 (GND), U$3.GND@2 (GND), U$3.GND@3 (GND), U$3.GND@4 (GND)
unnamed: D1.A, R1.2
unnamed: D4.A, R4.2
unnamed: D2.A, R2.2
unnamed: D3.A, R3.2
OUTPUT_1: JP1.VBUS, R2.1, U$1.OUT@1 (OUT), U$1.OUT@2 (OUT)
OUTPUT_2: JP2.VBUS, R3.1, U$2.OUT@1 (OUT), U$2.OUT@2 (OUT)
OUTPUT_3: JP3.VBUS, R4.1, U$3.OUT@1 (OUT), U$3.OUT@2 (OUT)

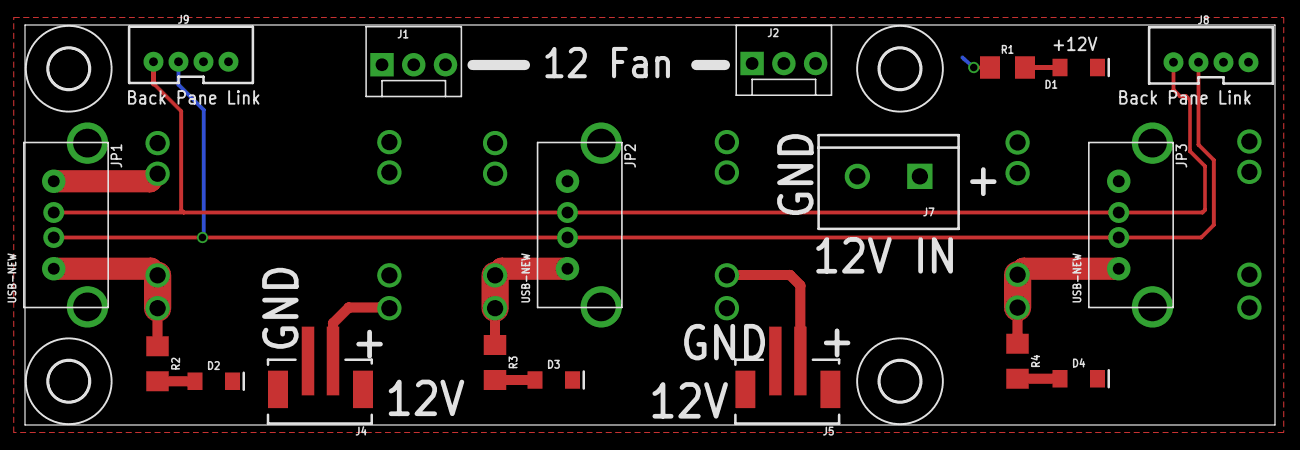
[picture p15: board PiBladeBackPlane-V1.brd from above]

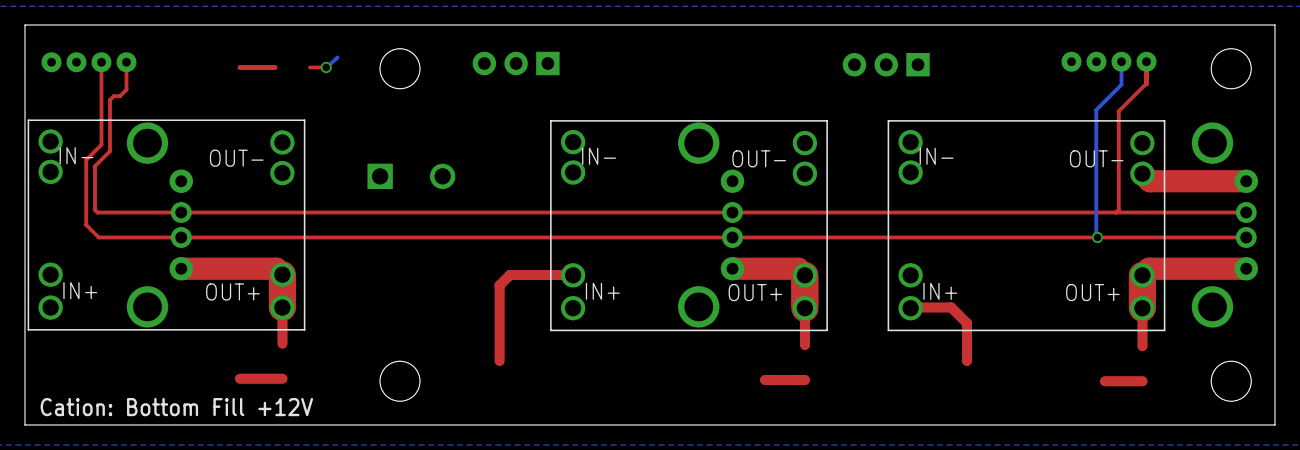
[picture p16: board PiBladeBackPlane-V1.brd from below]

Board: 2 copper layers, 100.0 x 32.0 mm, 25 parts (6 on the bottom side), 11 nets.

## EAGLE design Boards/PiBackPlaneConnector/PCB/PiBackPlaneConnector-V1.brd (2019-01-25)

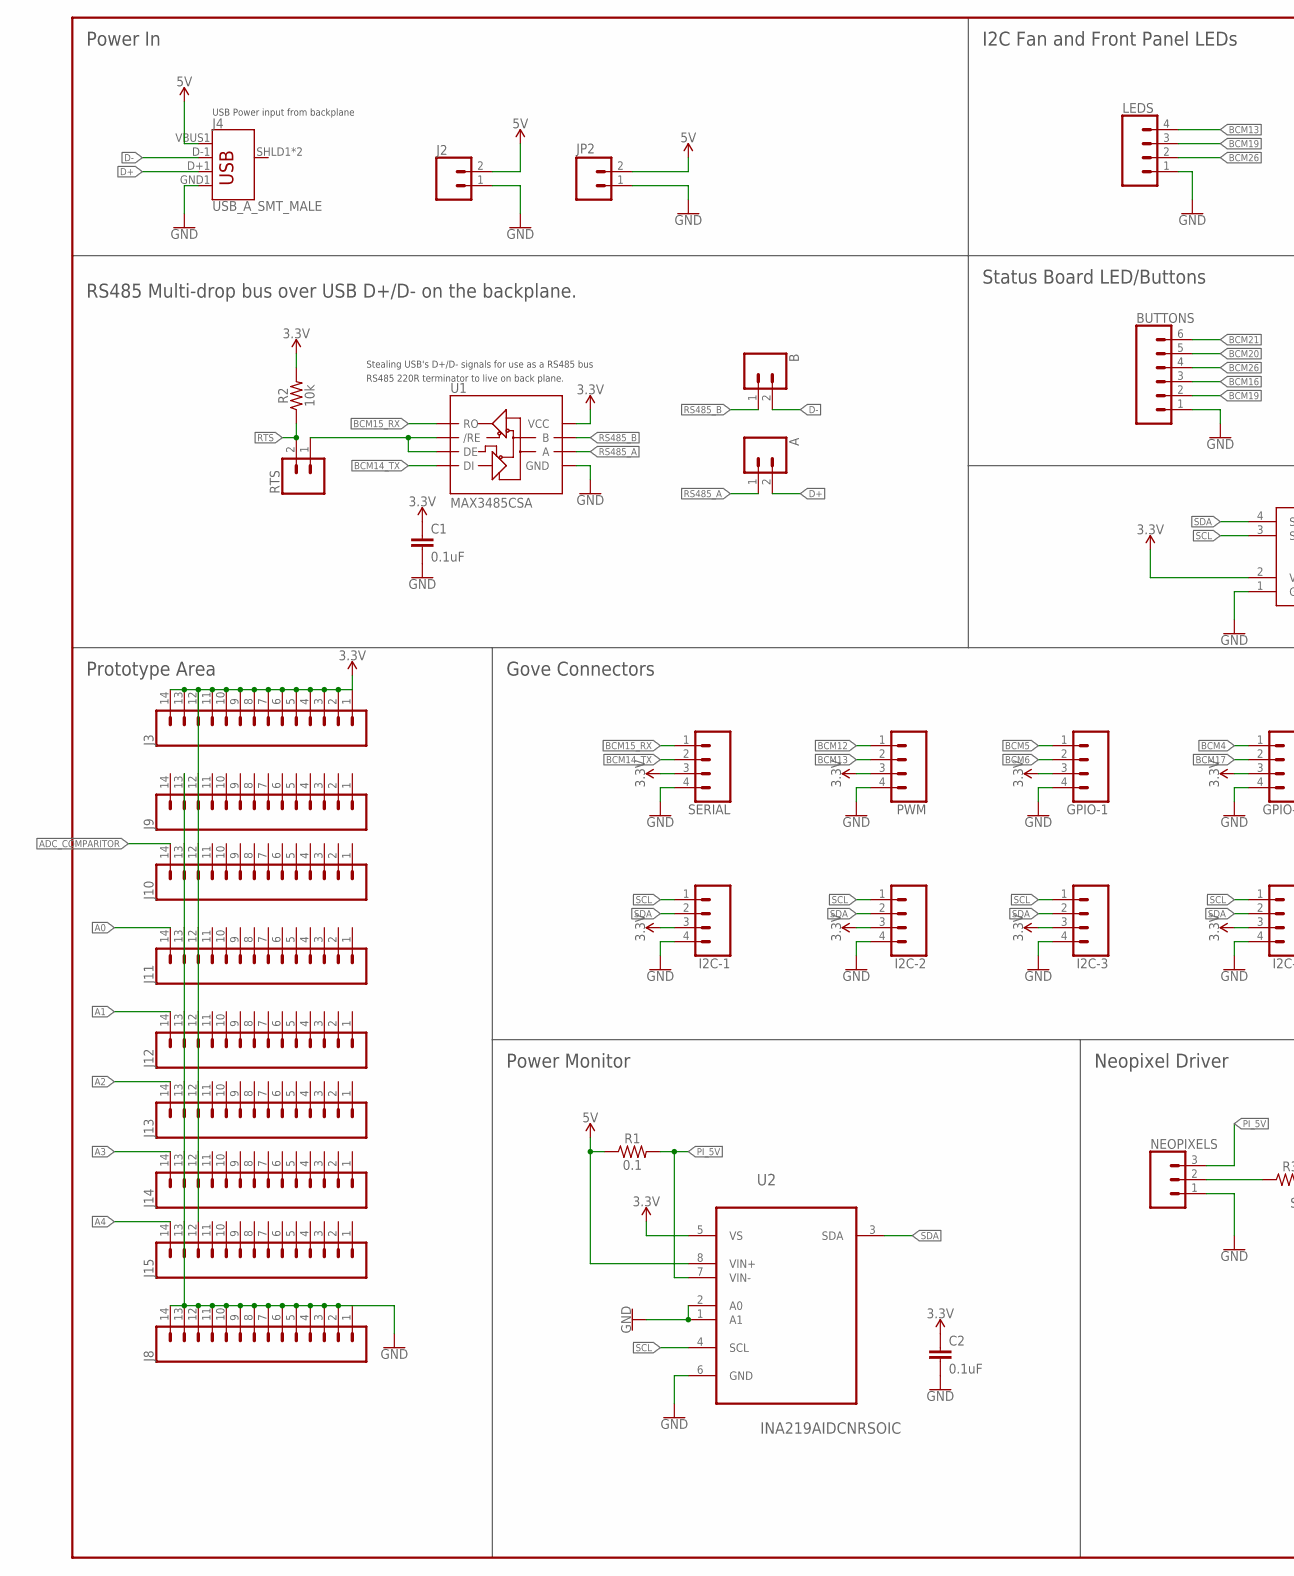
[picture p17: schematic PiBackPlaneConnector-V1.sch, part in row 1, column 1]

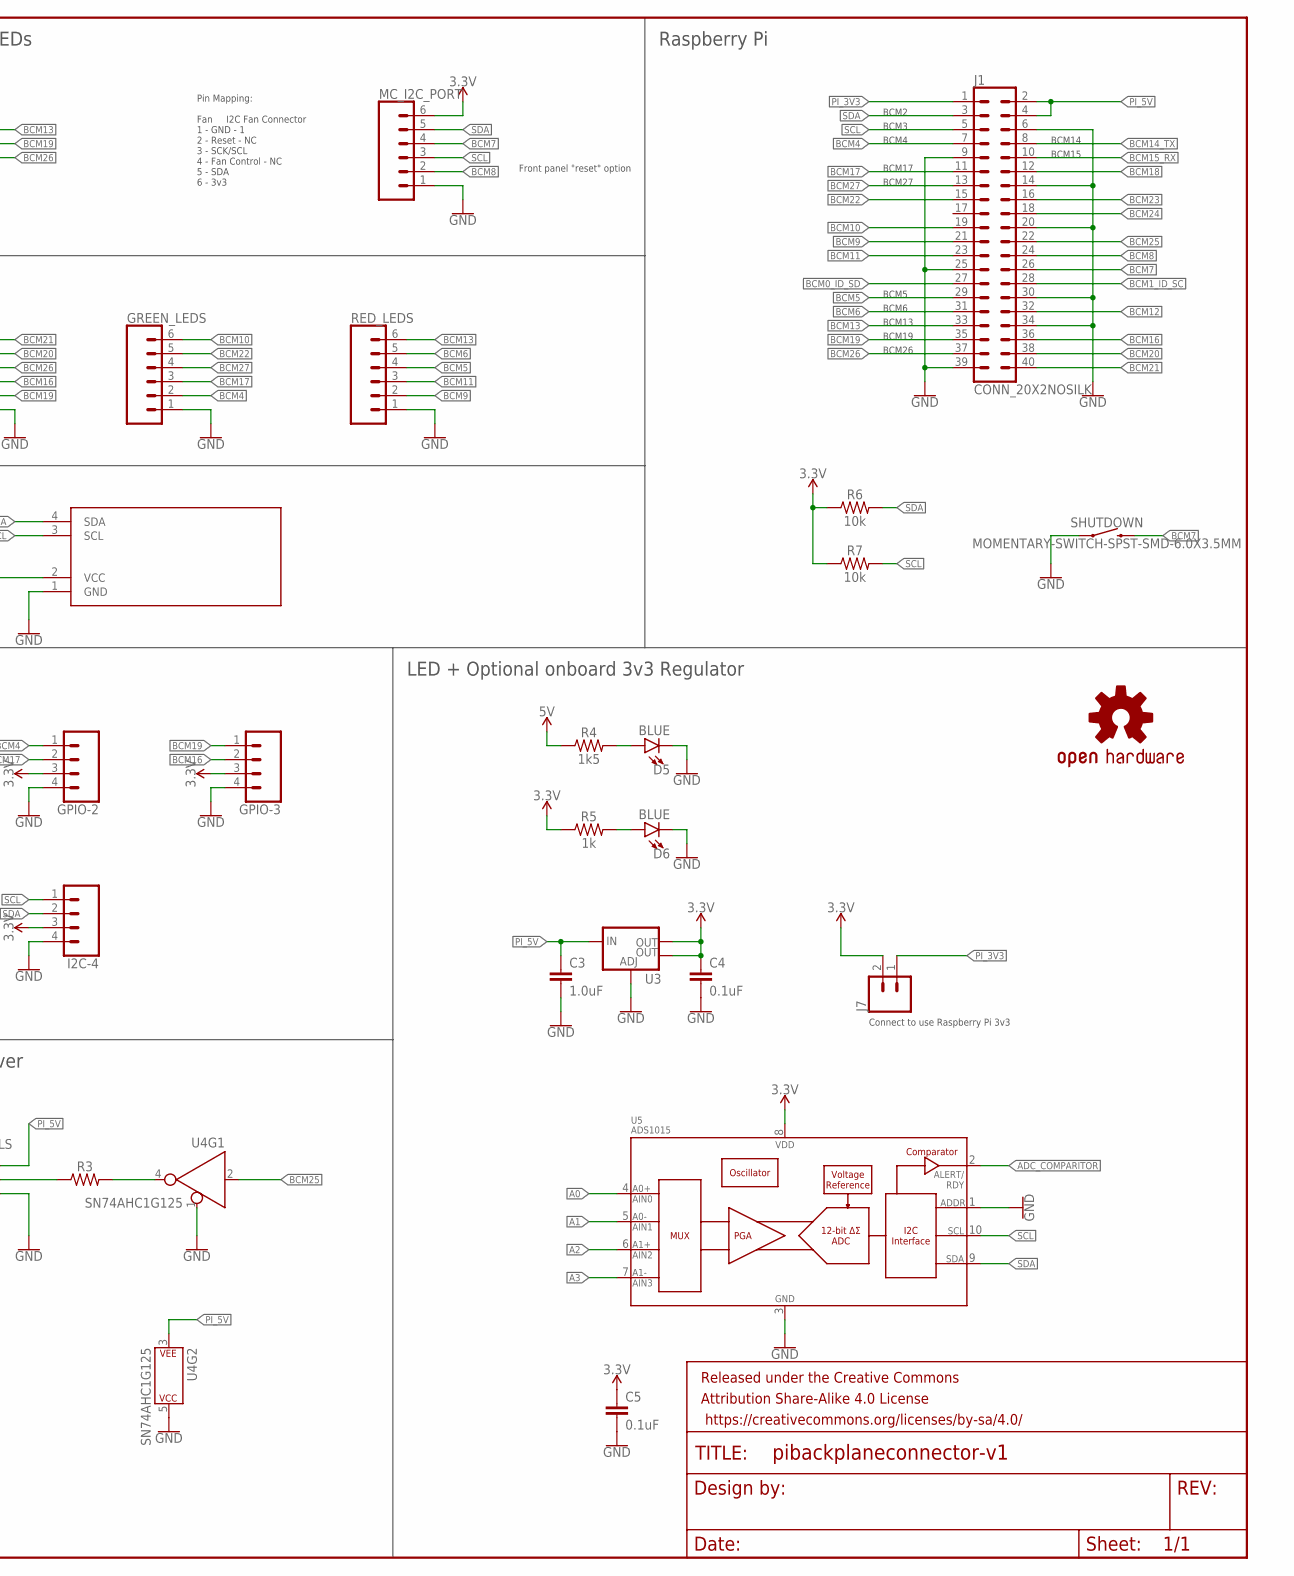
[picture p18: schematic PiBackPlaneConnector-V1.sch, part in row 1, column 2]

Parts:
A: CONN_02; 1X02
B: CONN_02; 1X02
BUTTONS: CONN_06SMD-1MM; 1X06-1MM
C1, C2, C4, C5: 0.1uF; 0805
C3: 1.0uF; 0805
D5, D6: BLUE; LED-1206
DISPLAY: DISPLAY0.91_INCH_DISPLAY; I2C_DISPLAY_0.91_INCH
FRAME1: FRAME-LEDGER; CREATIVE_COMMONS
GPIO-1, GPIO-2, GPIO-3: CONN_04JST-PTH-VERT; JST-4-PTH-VERT
GREEN_LEDS: CONN_06SMD-1MM; 1X06-1MM
I2C-1, I2C-2, I2C-3, I2C-4: CONN_04JST-PTH-VERT; JST-4-PTH-VERT
J1: CONN_20X2NOSILK; 2X20_NOSILK
J2: CONN_02POLAR; MOLEX-1X2
J3, J8: CONN_14; 1X14
J4: USB_A_SMT_MALE; USB-A-SMT-MALE
J7: CONN_02; 1X02
J9, J10, J11, J12, J13, J14, J15: CONN_14NO_SILK; 1X14_NO_SILK
JP2: M025MM; SCREWTERMINAL-5MM-2@1
LEDS: CONN_04SMD2; 1X04_1MM_RA
LOGO1: OSHW-LOGOM; OSHW-LOGO-M
MC_I2C_PORT: CONN_06SMD-1MM; 1X06-1MM
NEOPIXELS: CONN_03POLAR; MOLEX-1X3
PWM: CONN_04JST-PTH-VERT; JST-4-PTH-VERT
R1: 0.1; 1210
R2, R6, R7: 10k; 0805
R3: 0805
R4: 1k5; 0805
R5: 1k; 0805
RED_LEDS: CONN_06SMD-1MM; 1X06-1MM
RTS: CONN_02; 1X02
SERIAL: CONN_04JST-PTH-VERT; JST-4-PTH-VERT
SHUTDOWN: MOMENTARY-SWITCH-SPST-SMD-6.0X3.5MM; TACTILE_SWITCH_SMD_6.0X3.5MM
U1: MAX3485CSA; SO08
U2: INA219AIDCNRSOIC; SO08
U3: V_REG_LM1117SOT223; SOT223
U4: SN74AHC1G125; SOT23-5
U5: ADS1015; MSOP10

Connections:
3.3V: C1.1, C2.1, C4.1, C5.1, DISPLAY.2 (VCC), GPIO-1.3, GPIO-2.3, GPIO-3.3, I2C-1.3, I2C-2.3, I2C-3.3, I2C-4.3, J3.1, J3.2, J3.3, J3.4, J3.5, J3.6, J3.7, J3.8, J3.9, J3.10, J3.11, J3.12, J3.13, J3.14, J7.2, J9.12, J10.12, J11.12, J12.12, J13.12, J14.12, J15.12, MC_I2C_PORT.6, PWM.3, R2.2, R5.1, R6.1, R7.1, SERIAL.3, U1.8 (VCC), U2.5 (VS), U3.2 (OUT), U3.4 (OUT), U5.8 (VDD)
5V: J2.2, J4.VBUS1 (VBUS), JP2.2, R1.1, R4.1, U2.8 (VIN+)
A0: J11.14, U5.4 (AIN0)
A1: J12.14, U5.5 (AIN1)
A2: J13.14, U5.6 (AIN2)
A3: J14.14, U5.7 (AIN3)
A4: J15.14
ADC_COMPARITOR: J10.14, U5.2 (ALERT/RDY)
BCM0_ID_SD: J1.27
BCM1_ID_SC: J1.28
BCM4: GPIO-2.1, GREEN_LEDS.2, J1.7
BCM5: GPIO-1.1, J1.29, RED_LEDS.4
BCM6: GPIO-1.2, J1.31, RED_LEDS.5
BCM7: J1.26, MC_I2C_PORT.4, SHUTDOWN.2
BCM8: J1.24, MC_I2C_PORT.2
BCM9: J1.21, RED_LEDS.2
BCM10: GREEN_LEDS.6, J1.19
BCM11: J1.23, RED_LEDS.3
BCM12: J1.32, PWM.1
BCM13: J1.33, LEDS.4, PWM.2, RED_LEDS.6
BCM14_TX: J1.8, SERIAL.2, U1.4 (DI)
BCM15_RX: J1.10, SERIAL.1, U1.1 (RO)
BCM16: BUTTONS.3, GPIO-3.2, J1.36
BCM17: GPIO-2.2, GREEN_LEDS.3, J1.11
BCM18: J1.12
BCM19: BUTTONS.2, GPIO-3.1, J1.35, LEDS.3
BCM20: BUTTONS.5, J1.38
BCM21: BUTTONS.6, J1.40
BCM22: GREEN_LEDS.5, J1.15
BCM23: J1.16
BCM24: J1.18
BCM25: J1.22, U4.2 (A)
BCM26: BUTTONS.4, J1.37, LEDS.2
BCM27: GREEN_LEDS.4, J1.13
D+: A.2, J4.D+1 (D+)
D-: B.2, J4.D-1 (D-)
GND: BUTTONS.1, C1.2, C2.2, C3.2, C4.2, C5.2, D5.C, D6.C, DISPLAY.1 (GND), GPIO-1.4, GPIO-2.4, GPIO-3.4, GREEN_LEDS.1, I2C-1.4, I2C-2.4, I2C-3.4, I2C-4.4, J1.6, J1.9, J1.14, J1.20, J1.25, J1.30, J1.34, J1.39, J2.1, J4.GND1 (GND), J8.1, J8.2, J8.3, J8.4, J8.5, J8.6, J8.7, J8.8, J8.9, J8.10, J8.11, J8.12, J8.13, J8.14, J9.13, J10.13, J11.13, J12.13, J13.13, J14.13, J15.13, JP2.1, LEDS.1, MC_I2C_PORT.1, NEOPIXELS.1, PWM.4, RED_LEDS.1, SERIAL.4, SHUTDOWN.1, U1.5 (GND), U2.1 (A1), U2.2 (A0), U2.6 (GND), U3.1 (ADJ), U4.1 (!EN), U4.5 (P$V+), U5.1 (ADDR), U5.3 (VSS)
unnamed: D6.A, R5.2
unnamed: D5.A, R4.2
unnamed: RTS.1, U1.2 (/RE), U1.3 (DE)
unnamed: NEOPIXELS.2, R3.1
unnamed: R3.2, U4.4 (Y)
PI_3V3: J1.1, J7.1
PI_5V: C3.1, J1.2, J1.4, NEOPIXELS.3, R1.2, U2.7 (VIN-), U3.3 (IN), U4.3 (P$V-)
RS485_A: A.1, U1.6 (A)
RS485_B: B.1, U1.7 (B)
RTS: R2.1, RTS.2
SCL: DISPLAY.3 (SCL), I2C-1.1, I2C-2.1, I2C-3.1, I2C-4.1, J1.5, MC_I2C_PORT.3, R7.2, U2.4 (SCL), U5.10 (SCL)
SDA: DISPLAY.4 (SDA), I2C-1.2, I2C-2.2, I2C-3.2, I2C-4.2, J1.3, MC_I2C_PORT.5, R6.2, U2.3 (SDA), U5.9 (SDA)

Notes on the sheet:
BCM13
BCM6
BCM5
BCM26
BCM19
Stealing USB's D+/D- signals for use as a RS485 bus
RS485 220R terminator to live on back plane.
Connect to use Raspberry Pi 3v3
USB Power input from backplane
BCM14
BCM15
BCM2
BCM3
BCM4
BCM17
BCM27
Pin Mapping: Fan I2C Fan Connector 1 - GND - 1 2 - Reset - NC 3 - SCK/SCL 4 - Fan Control - NC 5 - SDA 6 - 3v3
Power In
RS485 Multi-drop bus over USB D+/D- on the backplane.
Raspberry Pi
Prototype Area
Gove Connectors
LED + Optional onboard 3v3 Regulator
Status Board LED/Buttons
I2C Fan and Front Panel LEDs
Neopixel Driver
Power Monitor
Front panel "reset" option

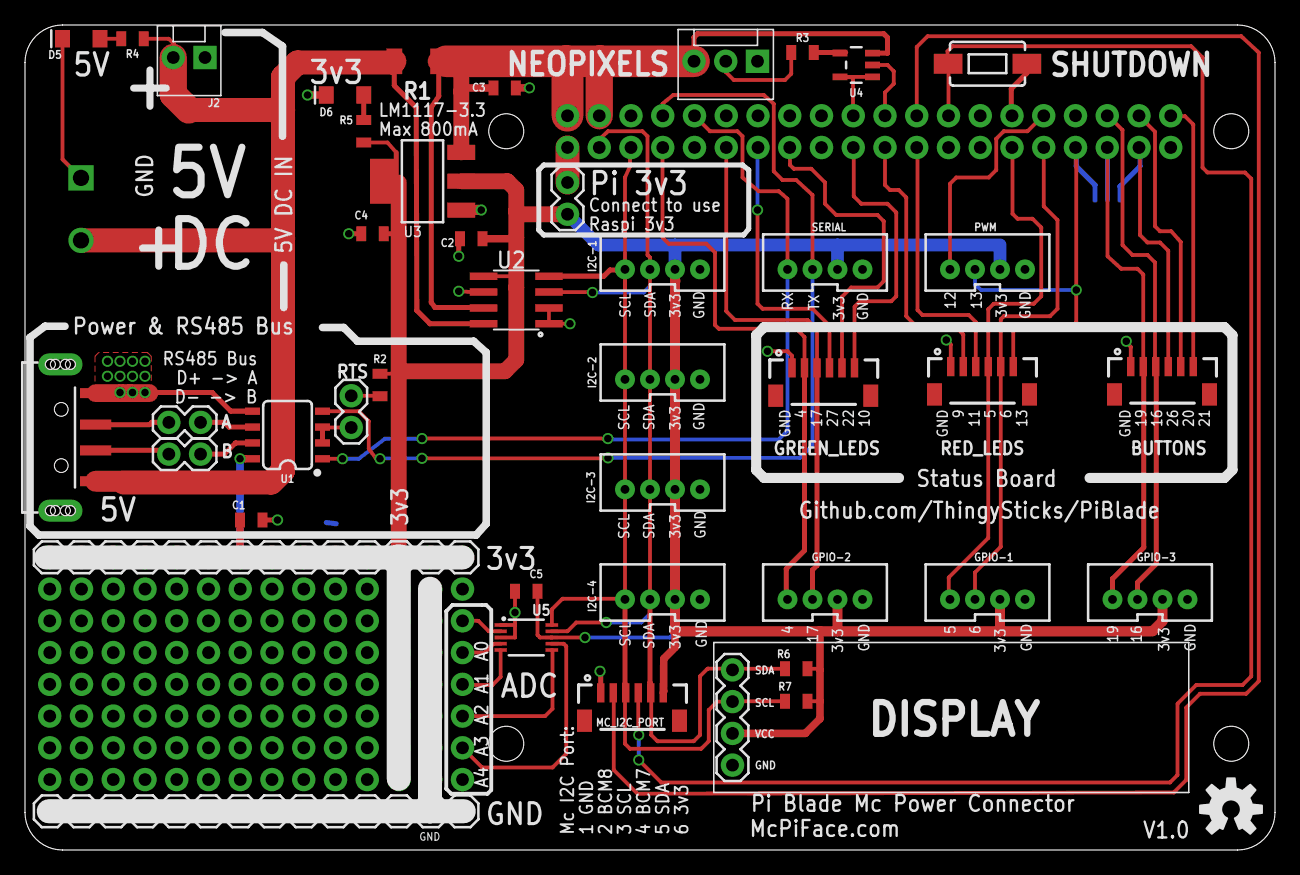
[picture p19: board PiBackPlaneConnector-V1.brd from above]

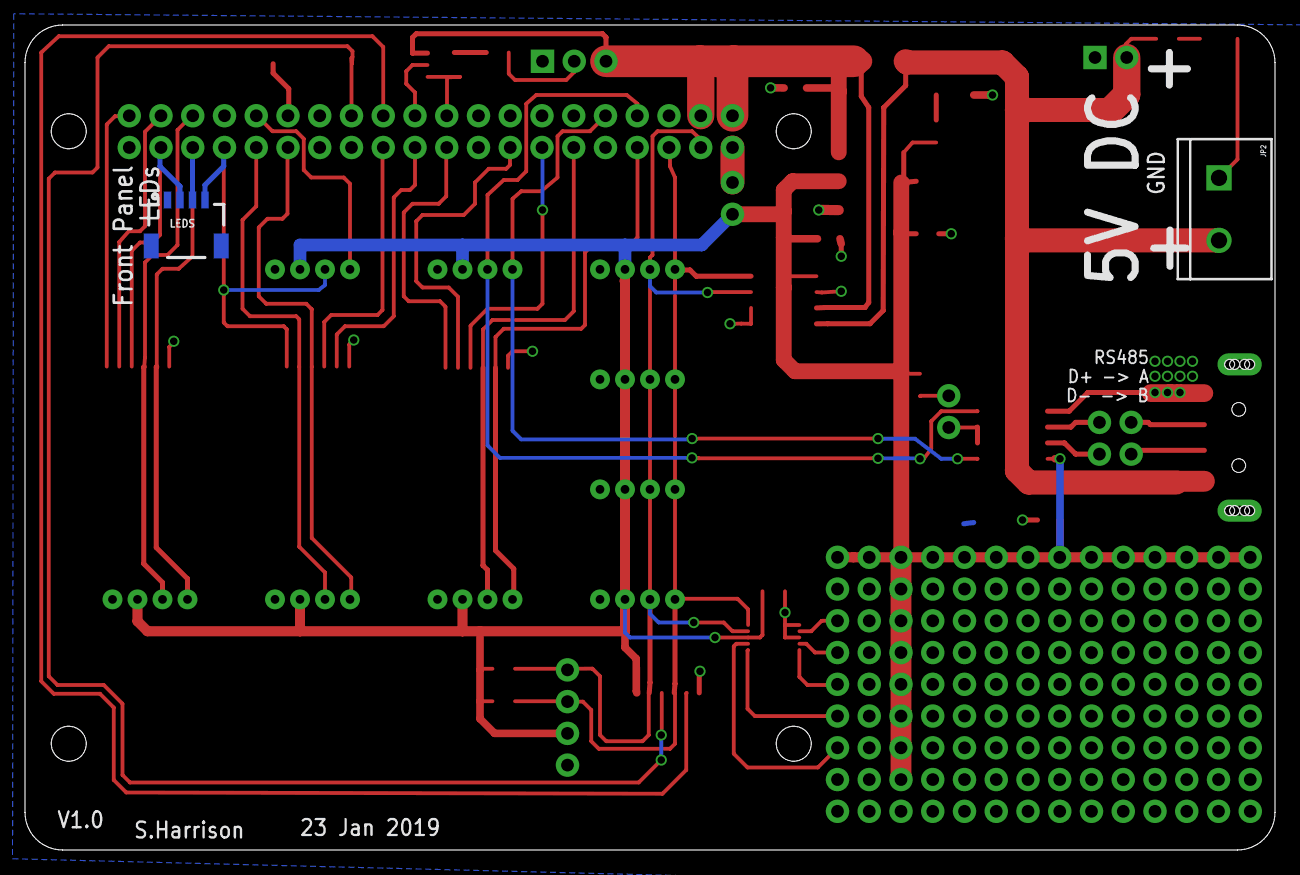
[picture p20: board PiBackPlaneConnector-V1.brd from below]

Board: 2 copper layers, 100.0 x 66.0 mm, 55 parts (3 on the bottom side), 43 nets.

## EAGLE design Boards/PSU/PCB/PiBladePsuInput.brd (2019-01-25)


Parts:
12V: RELAYSONGLE; SRD-5VDC-SL-C
C1, C3: 1.0uF; 0805
C2, C4, C5, C6: 0.1uF; 0805
D1, D2, D3: 1A/23V/620mV; SOD-323
D4, D5, D6, D7, D8, D9: BLUE; LED-1206
J1: CONN_20X2NOSILK; 2X20_NOSILK
J2: CONN_06SMD-1MM; 1X06-1MM
J3: CONN_04SMD2; 1X04_1MM_RA
JP1: POWER_JACKTOE; POWER_JACK_SMD_OVERPASTE_TOE
JP2, JP3, JP4, JP5: M025MM; SCREWTERMINAL-5MM-2
JP6: USB-NEW; USB-A-VERTICAL
LOGO1: OSHW-LOGOM; OSHW-LOGO-M
Q1, Q2, Q3: 220mA/50V/3.5Ω; SOT23-3
R1, R2: 4k7; 0805
R3, R4, R5, R6, R11, R12: 0805
R7: 0.05; 2512
R8, R9, R10: 1M; 0805
U1: INA219AIDCNRSOIC; SO08
U2: R-78E5.0-1.0; DC-DC_CONVERTER_78XX
U3: V_REG_LM1117SOT223; SOT223
U4: Tiny85-20-SMT; SO08-EIAJ
U$2, U$3: RELAYSONGLE; SRD-5VDC-SL-C

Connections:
3.3V: C4.1, C5.1, C6.1, J2.1, R1.1, R2.1, R5.1, U1.5 (VS), U3.2 (OUT), U3.4 (OUT), U4.8 (VCC)
5V: 12V.COIL2, C2.1, C3.1, D1.C, D2.C, D3.C, J1.2, J1.4, JP6.VBUS, R4.1, U2.VOUT (OUT), U3.3 (IN), U$2.COIL2, U$3.COIL2
12V: 12V.COMMON (MAIN), C1.1, R7.P$2 (2), U1.7 (VIN-), U2.VIN (IN), U$2.COMMON (MAIN), U$3.COMMON (MAIN)
CH1_ENABLE: J1.33, J2.5, J3.2, Q1.1 (G), R10.1, U4.1 (PB5(NRES))
CH2_ENABLE: J1.35, J3.3, Q2.1 (G), R9.1, U4.2 (PB3(ADC3))
CH3_ENABLE: J1.37, J3.4, Q3.1 (G), R8.1, U4.3 (PB4(ADC2))
GND: C1.2, C2.2, C3.2, C4.2, C5.2, C6.2, D4.C, D5.C, D6.C, D7.C, D8.C, D9.C, J1.6, J1.9, J1.14, J1.20, J1.25, J1.30, J1.34, J1.39, J2.6, J3.1, JP1.GND (GNDBREAK), JP1.P$4 (GND), JP2.1, JP3.2, JP4.2, JP5.2, JP6.GND, Q1.2 (S), Q2.2 (S), Q3.2 (S), R8.2, R9.2, R10.2, U1.1 (A1), U1.2 (A0), U1.6 (GND), U2.GND, U3.1 (ADJ), U4.4 (GND)
MISO: J2.3, U4.6 (PB1(MISO))
unnamed: D4.A, R3.2
unnamed: D6.A, R5.2
unnamed: D7.A, R6.2
unnamed: D5.A, R4.2
unnamed: D8.A, R11.2
unnamed: D9.A, R12.2
unnamed: D3.A, Q3.3 (D), U$3.COIL1
unnamed: D2.A, Q2.3 (D), U$2.COIL1
unnamed: 12V.COIL1, D1.A, Q1.3 (D)
OUT1: 12V.OPEN (NO), JP3.1, R6.1
OUT2: JP4.1, R11.1, U$2.OPEN (NO)
OUT3: JP5.1, R12.1, U$3.OPEN (NO)
SCL: J1.5, J2.4, R1.2, U1.4 (SCL), U4.7 (PB2(SCK/ADC1))
SDA: J1.3, J2.2, R2.2, U1.3 (SDA), U4.5 (PB0(MOSI))
VIN: JP1.VIN0 (PWR), JP2.2, R3.1, R7.P$1 (1), U1.8 (VIN+)

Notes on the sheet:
BCM13
BCM6
BCM5
BCM26
BCM19



Board: 2 copper layers, 85.0 x 56.0 mm, 47 parts (2 on the bottom side), 23 nets.

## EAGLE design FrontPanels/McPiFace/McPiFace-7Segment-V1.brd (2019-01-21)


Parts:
C1, C2, C3, C4, C5, C6, C7, C8, C9, C10, C11, C12, C13, C14, C15: 1.0uF; 0805-CAP
JP3, JP4: 3-PIN SMD; JST-3-SMD
LED1, LED2, LED3, LED4, LED5, LED6, LED7, LED8, LED9, LED10, LED11, LED12, LED13, LED14, LED15, LED16, LED17, LED18, LED19, LED20, LED21, LED22, LED23, LED24, LED25, LED26, LED27, LED28, LED29, LED30, LED31, LED32, LED33, LED34: WS2812B5050; WS2812B
LOGO1: OSHW-LOGOL; OSHW-LOGO-L
R1: 0805

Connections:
5V: C1.1, C2.1, C3.1, C4.1, C5.1, C6.1, C7.1, C8.1, C9.1, C10.1, C11.1, C12.1, C13.1, C14.1, C15.1, JP3.3, JP4.3, LED1.1-VDD (VDD), LED2.1-VDD (VDD), LED3.1-VDD (VDD), LED4.1-VDD (VDD), LED5.1-VDD (VDD), LED6.1-VDD (VDD), LED7.1-VDD (VDD), LED8.1-VDD (VDD), LED9.1-VDD (VDD), LED10.1-VDD (VDD), LED11.1-VDD (VDD), LED12.1-VDD (VDD), LED13.1-VDD (VDD), LED14.1-VDD (VDD), LED15.1-VDD (VDD), LED16.1-VDD (VDD), LED17.1-VDD (VDD), LED18.1-VDD (VDD), LED19.1-VDD (VDD), LED20.1-VDD (VDD), LED21.1-VDD (VDD), LED22.1-VDD (VDD), LED23.1-VDD (VDD), LED24.1-VDD (VDD), LED25.1-VDD (VDD), LED26.1-VDD (VDD), LED27.1-VDD (VDD), LED28.1-VDD (VDD), LED29.1-VDD (VDD), LED30.1-VDD (VDD), LED31.1-VDD (VDD), LED32.1-VDD (VDD), LED33.1-VDD (VDD), LED34.1-VDD (VDD)
DIN: JP3.2, R1.1
DOUT: JP4.2, LED15.2-DOUT (DO)
GND: C1.2, C2.2, C3.2, C4.2, C5.2, C6.2, C7.2, C8.2, C9.2, C10.2, C11.2, C12.2, C13.2, C14.2, C15.2, JP3.1, JP4.1, LED1.3-GND (GND), LED2.3-GND (GND), LED3.3-GND (GND), LED4.3-GND (GND), LED5.3-GND (GND), LED6.3-GND (GND), LED7.3-GND (GND), LED8.3-GND (GND), LED9.3-GND (GND), LED10.3-GND (GND), LED11.3-GND (GND), LED12.3-GND (GND), LED13.3-GND (GND), LED14.3-GND (GND), LED15.3-GND (GND), LED16.3-GND (GND), LED17.3-GND (GND), LED18.3-GND (GND), LED19.3-GND (GND), LED20.3-GND (GND), LED21.3-GND (GND), LED22.3-GND (GND), LED23.3-GND (GND), LED24.3-GND (GND), LED25.3-GND (GND), LED26.3-GND (GND), LED27.3-GND (GND), LED28.3-GND (GND), LED29.3-GND (GND), LED30.3-GND (GND), LED31.3-GND (GND), LED32.3-GND (GND), LED33.3-GND (GND), LED34.3-GND (GND)
unnamed: LED1.2-DOUT (DO), LED2.4-DIN (DI)
unnamed: LED1.4-DIN (DI), R1.2
unnamed: LED2.2-DOUT (DO), LED3.4-DIN (DI)
unnamed: LED3.2-DOUT (DO), LED4.4-DIN (DI)
unnamed: LED4.2-DOUT (DO), LED5.4-DIN (DI)
unnamed: LED5.2-DOUT (DO), LED6.4-DIN (DI)
unnamed: LED6.2-DOUT (DO), LED7.4-DIN (DI)
unnamed: LED7.2-DOUT (DO), LED8.4-DIN (DI)
unnamed: LED8.2-DOUT (DO), LED9.4-DIN (DI)
unnamed: LED9.2-DOUT (DO), LED10.4-DIN (DI)
unnamed: LED10.2-DOUT (DO), LED11.4-DIN (DI)
unnamed: LED11.2-DOUT (DO), LED17.4-DIN (DI)
unnamed: LED17.2-DOUT (DO), LED18.4-DIN (DI)
unnamed: LED18.2-DOUT (DO), LED19.4-DIN (DI)
unnamed: LED19.2-DOUT (DO), LED20.4-DIN (DI)
unnamed: LED20.2-DOUT (DO), LED21.4-DIN (DI)
unnamed: LED21.2-DOUT (DO), LED22.4-DIN (DI)
unnamed: LED22.2-DOUT (DO), LED23.4-DIN (DI)
unnamed: LED23.2-DOUT (DO), LED24.4-DIN (DI)
unnamed: LED24.2-DOUT (DO), LED25.4-DIN (DI)
unnamed: LED16.4-DIN (DI), LED25.2-DOUT (DO)
unnamed: LED16.2-DOUT (DO), LED26.4-DIN (DI)
unnamed: LED26.2-DOUT (DO), LED27.4-DIN (DI)
unnamed: LED27.2-DOUT (DO), LED28.4-DIN (DI)
unnamed: LED28.2-DOUT (DO), LED29.4-DIN (DI)
unnamed: LED29.2-DOUT (DO), LED30.4-DIN (DI)
unnamed: LED30.2-DOUT (DO), LED31.4-DIN (DI)
unnamed: LED31.2-DOUT (DO), LED32.4-DIN (DI)
unnamed: LED32.2-DOUT (DO), LED33.4-DIN (DI)
unnamed: LED33.2-DOUT (DO), LED34.4-DIN (DI)
unnamed: LED12.4-DIN (DI), LED34.2-DOUT (DO)
unnamed: LED12.2-DOUT (DO), LED13.4-DIN (DI)
unnamed: LED13.2-DOUT (DO), LED14.4-DIN (DI)
unnamed: LED14.2-DOUT (DO), LED15.4-DIN (DI)



Board: 2 copper layers, 44.0 x 88.0 mm, 53 parts (19 on the bottom side), 38 nets.

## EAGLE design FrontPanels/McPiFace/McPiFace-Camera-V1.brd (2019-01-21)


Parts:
D1, D2, D3: LED1206-BOTTOM-1.6MM; LED-1206-BOTTOM-1.6MM
D4, D5, D6, D7, D8, D9, D10, D11, D12, D13, D14, D15: WHITE; LED-1206
D16, D17, D18, D19, D20, D21, D22, D23, D24, D25, D26, D27: RED; LED-1206
D28, D29, D30, D31, D32, D33, D34, D35, D36, D37, D38, D39: IR; LED-1206
H3, H4: MOUNT-HOLE2.8; 2,8
J1: CONN_04SMD2; 1X04_1MM_RA
JP1: M06SMD-1MM; 1X06-1MM
JP2: M02-JST-2MM-SMT; JST-2-SMD
LOGO1: OSHW-LOGOL; OSHW-LOGO-L
Q1, Q2, Q3: MOSFET-NCHANNELBSS123LT1G; SOT23-3
R1, R2, R3, R7, R8, R9, R10, R11, R12, R13, R14, R15, R16, R17, R18: 1206
R4, R5, R6: 10R; 1206

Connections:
GND: D1.C, D2.C, D3.C, J1.1, JP1.1, JP2.1 (2), Q1.2 (S), Q2.2 (S), Q3.2 (S)
IR_LEDS: D28.C, D29.C, D30.C, D31.C, D32.C, D33.C, D34.C, D35.C, D36.C, D37.C, D38.C, D39.C, Q1.3 (D)
LEDS1: D4.C, D5.C, D6.C, D7.C, D8.C, D9.C, D10.C, D11.C, D12.C, D13.C, D14.C, D15.C, Q2.3 (D)
LEDS2: D16.C, D17.C, D18.C, D19.C, D20.C, D21.C, D22.C, D23.C, D24.C, D25.C, D26.C, D27.C, Q3.3 (D)
unnamed: D1.A, R3.2
unnamed: D2.A, R2.2
unnamed: D3.A, R1.2
unnamed: J1.2, R1.1
unnamed: J1.3, R2.1
unnamed: J1.4, R3.1
unnamed: JP1.2, R4.1
unnamed: JP1.3, R5.1
unnamed: JP1.4, R6.1
unnamed: Q3.1 (G), R6.2
unnamed: Q2.1 (G), R5.2
unnamed: Q1.1 (G), R4.2
unnamed: D13.A, D14.A, D15.A, R10.1
unnamed: D10.A, D11.A, D12.A, R9.1
unnamed: D7.A, D8.A, D9.A, R8.1
unnamed: D4.A, D5.A, D6.A, R7.1
unnamed: D16.A, D17.A, D18.A, R11.1
unnamed: D19.A, D20.A, D21.A, R12.1
unnamed: D22.A, D23.A, D24.A, R13.1
unnamed: D25.A, D26.A, D27.A, R14.1
unnamed: D28.A, D29.A, D30.A, R15.1
unnamed: D31.A, D32.A, D33.A, R16.1
unnamed: D34.A, D35.A, D36.A, R17.1
unnamed: D37.A, D38.A, D39.A, R18.1
VCC: JP1.5, JP1.6, JP2.2 (1), R7.2, R8.2, R9.2, R10.2, R11.2, R12.2, R13.2, R14.2, R15.2, R16.2, R17.2, R18.2



Board: 2 copper layers, 88.0 x 88.0 mm, 66 parts (28 on the bottom side), 29 nets.

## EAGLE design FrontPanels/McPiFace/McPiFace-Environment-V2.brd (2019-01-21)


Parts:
C1: 1.0uF; 0805
C2, C3, C4, C5, C7: 0.1uF; 0805
C6: 10uF; EIA3216
D1, D2, D3: LED1206-BOTTOM-1.6MM; LED-1206-BOTTOM-1.6MM
H3, H4: MOUNT-HOLE2.8; 2,8
IC1: BME680
J1: Pi LEDs; 1X04_1MM_RA
JP1: Pi I2C; 1X06-1MM
JP2: Ext.Sensors; 1X06-1MM
LOGO1: OSHW-LOGOL; OSHW-LOGO-L
R1, R2, R3: 1k5; 0805
R4: oR; 0805
R5, R6: 4k7; 0805
R7, R8: 10k; 0805
U1: SPW2430HR5H-B
U2: ADS1015; MSOP10
U3: LIS3DH; LGA-16-3X3
U$1: TCS3472; FN-6

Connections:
3.3V: C1.1, C2.1, C3.1, C4.1, C5.1, C6.A (+), C7.1, IC1.2 (CSB), IC1.6 (VDDIO), IC1.8 (VDD), JP1.6, JP2.6, R5.2, R6.2, R7.2, U1.4 (VDD), U2.8 (VDD), U3.1 (VDDIO), U3.14 (VDD), U$1.1 (VDD)
ACCEL_INT: U3.11 (INT1)
ACCEL_INT2: U3.9 (INT2)
AIN1: JP2.2, U2.5 (AIN1), U3.15 (ADC2)
AIN2: JP2.3, U2.6 (AIN2), U3.13 (ADC3)
AIN3: JP2.4, U2.7 (AIN3)
ALERT: R4.1, U2.2 (ALERT/RDY)
D1: JP1.5, JP2.5, R4.2
GND: C1.2, C2.2, C3.2, C4.2, C5.2, C6.C (-), C7.2, D1.C, D2.C, D3.C, IC1.1 (GND), IC1.5 (SDO), IC1.7 (GND), J1.1, JP1.1, JP2.1, R8.1, U1.2 (GND), U1.3 (GND), U2.1 (ADDR), U2.3 (VSS), U3.5 (GND), U3.10 (RES), U3.12 (GND), U$1.3 (GND)
LIGHT_INT: JP1.4, U$1.5 (INT)
MIC_ANALOG: U1.1 (OUTPUT), U2.4 (AIN0), U3.16 (ADC1)
unnamed: D1.A, R3.2
unnamed: D2.A, R2.2
unnamed: D3.A, R1.2
unnamed: J1.2, R1.1
unnamed: J1.3, R2.1
unnamed: J1.4, R3.1
unnamed: R8.2, U3.7 (SA0/SDO)
unnamed: R7.1, U3.8 (!CS!/MODE)
SCL: IC1.4 (SCK), JP1.3, R5.1, U2.10 (SCL), U3.4 (SCL/SPC), U$1.2 (SCL)
SDA: IC1.3 (SDI), JP1.2, R6.1, U2.9 (SDA), U3.6 (SDA/SDI), U$1.6 (SDA)

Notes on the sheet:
Addr: 1001000 (0x48)
Addr: 0x5A
I2C select
ADC Range 1200mV +/- 400mV



Board: 2 copper layers, 44.0 x 88.0 mm, 29 parts (15 on the bottom side), 19 nets.

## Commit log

2019-01-05 V1.1 PCB as send to DirtyPCBs. Increased mounting hole size, moved OSH symbol to PCB read.
    [McPiFace-V1.brd, McPiFace-V1.sch]
2019-01-05 Base for Raspberry Pi (tested with 3), to fit front panel.
    [PiRackPiBase.stl]
2019-01-14 New PiFace front panels as sent to DirtyPCBs
    [McPiFace-60mmFan-V1.brd, McPiFace-60mmFan-V1.sch, McPiFace-Audio-V1.brd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]
2019-01-21 RGB LED panel.
    As sent to Dirty PCBs
    [McPiFace-RGBPanel-V1.brd, McPiFace-RGBPanel-V1.sch]
2019-01-21 Environment monitor V1 as send to Dirty PCBs.
    [McPiFace-Environment-V1.brd, McPiFace-Environment-V1.sch]
2019-01-21 Environment monitor V2 (maybe send to Dirty PCBs).
    [McPiFace-Environment-V2.brd, McPiFace-Environment-V2.sch]
2019-01-21 Pi Camera panel as send to Dirty PCBs.
    [McPiFace-Camera-V1.brd, McPiFace-Camera-V1.sch]
2019-01-21 RGB Seven Segment panel as send to Dirty PCBs.
    [McPiFace-7Segment-V1.brd, McPiFace-7Segment-V1.sch]
2019-01-21 V2 fan panel as send to Dirty PCBs
    [McPiFace-60mmFan-V2.brd, McPiFace-60mmFan-V2.sch]
2019-01-21 DC Input panel (as send to Dirty PCBs)
    [PiBladePsuInput.brd, PiBladePsuInput.sch]
2019-01-21 Added Particle Feather Ethernet board (unchecked)
    [McParticleEthernetFace-V1.brd, McParticleEthernetFace-V1.sch]
2019-01-21 Version 3 of fan controller with ATTiny85 to control and accelerometer to check for fan vibration (+ it includes a temperature sensor)
    [McPiFace-60mmFan-V3.brd, McPiFace-60mmFan-V3.sch]
2019-01-21 Fixed height of ethernet connector.
    Moved LEDs/connector as the frame clashes with that area of the panel.
    [McParticleEthernetFace-V1.brd]
2019-01-21 Update PSU input board: * Added LEDs. * Moved DC Jack input to a lower position to align with the USB board better.
    Updated DirtyPCBs
    [PiBladePsuInput.brd, PiBladePsuInput.sch]
2019-01-22 Added PCB images from DirtyPCBs.
2019-01-22 2 Pi's back to back mount.
    [PiRackPiLongBase.stl]
2019-01-25 Moved / Renamed PSU Input hat.
    [PiBladePsuInput.brd, PiBladePsuInput.sch]
2019-01-25 Backplane connector board with various IO for front panels, additional power connectors and a breakout board.
    [PiBackPlaneConnector-V1.brd, PiBackPlaneConnector-V1.sch]
2019-01-25 Start of back plane to distrubute power and RS485 bus.
    [PiBladeBackPlane-V1 .brd, PiBladeBackPlane-V1.sch]
2019-01-25 Front panel with mini oled display positioned to cover the USB connectors to prevent the USB ports being used.
    [McPiFace-MiniOled-USBCover-V1.brd, McPiFace-MiniOled-USBCover-V1.sch]
2019-01-25 Front panel with 0.91" OLED display in place of the name label (and name label moved).
    [McPiFace-MiniOled-V1.brd, McPiFace-MiniOled-V1.sch]
2019-01-25 Added images from schematic/pcbs and scripts to generate them.
    [McPiFace-60mmFan-V2.brd, McPiFace-Double-V1.brd, PiBladeBackPlane-V1.brd]

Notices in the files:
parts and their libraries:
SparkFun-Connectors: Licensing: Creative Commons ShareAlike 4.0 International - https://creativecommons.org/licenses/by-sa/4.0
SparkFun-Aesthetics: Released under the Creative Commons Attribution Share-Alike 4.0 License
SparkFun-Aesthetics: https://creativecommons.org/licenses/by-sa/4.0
